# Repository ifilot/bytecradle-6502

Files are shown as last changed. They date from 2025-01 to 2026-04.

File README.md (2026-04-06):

# ByteCradle 6502



The **ByteCradle 6502** is a **single-board computer (SBC)** platform designed
for understanding and experimenting with **simple operating systems** on **8-bit
hardware**. Built around the **WDC 65C02** microprocessor, it provides a
hands-on platform for studying **system initialization, memory management,
device interfacing, and file system handling**.

> [!NOTE]  
> The source code for the ByteCradle 6502 operating system for the Mini is found
> in [a separate repository](https://github.com/ifilot/bytecradle-6502-operating-system).

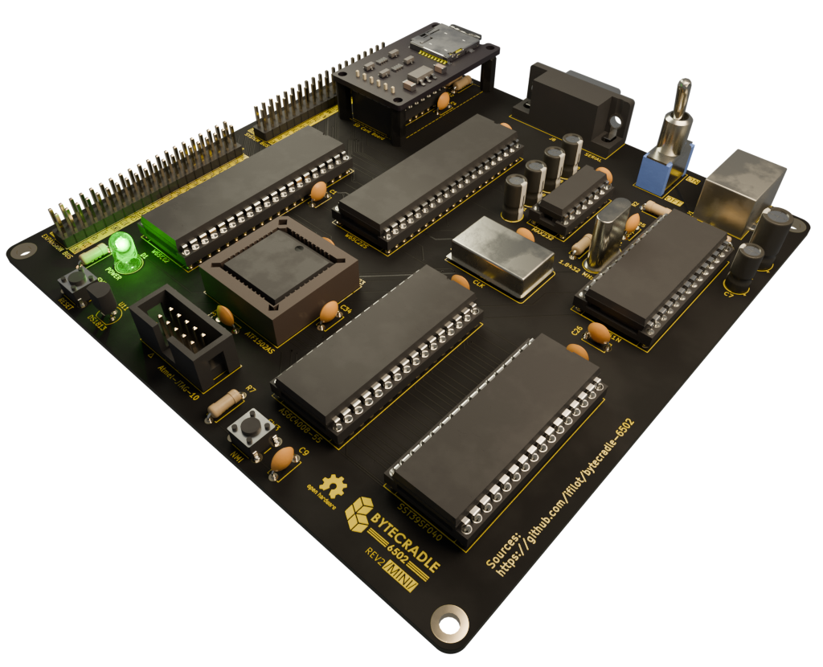
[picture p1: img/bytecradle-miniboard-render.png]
render top


## 📋 Table of Contents

- [BYTECRADLE 6502](#bytecradle-6502)
- [Overview](#overview)
  - [Shared Components](#shared-components)
- [Tier Comparison](#tier-comparison)
- [Obtaining PCBs](#obtaining-pcbs)
- [Download ROMs](#download-roms)
- [License](#license)
  - [Software](#software)
  - [Hardware](#hardware)
- [Contributing](#contributing)
- [Acknowledgements](#acknowledgements)

## Overview

Both SBCs share a common design philosophy — to provide a straightforward and
accessible 65C02 system, while exploring different levels of hardware
capability.

### Shared Components

- **CPU**: WDC 65C02
- **I/O**: WDC 65C51 Asynchronous Communications Interface Adapter (ACIA)

## Tier Comparison

This project offers two tiers of single board computers (SBCs), each tailored to
different levels of complexity and expandability:

- **Tiny SBC** (top): A simple, compact design ideal for learning or small
  embedded projects.
- **Mini SBC** (bottom): A more capable version with bank switching, SD card
  storage, and an expansion bus using the 65C22 Versatile Interface Adapter
  (VIA).

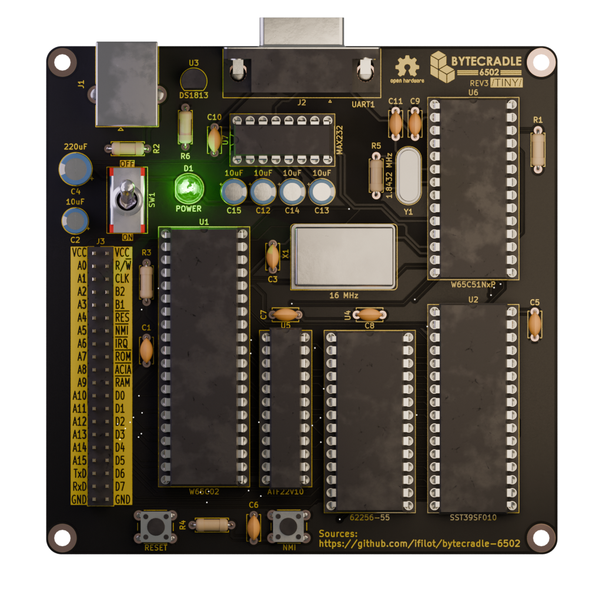
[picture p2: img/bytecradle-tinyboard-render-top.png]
render top


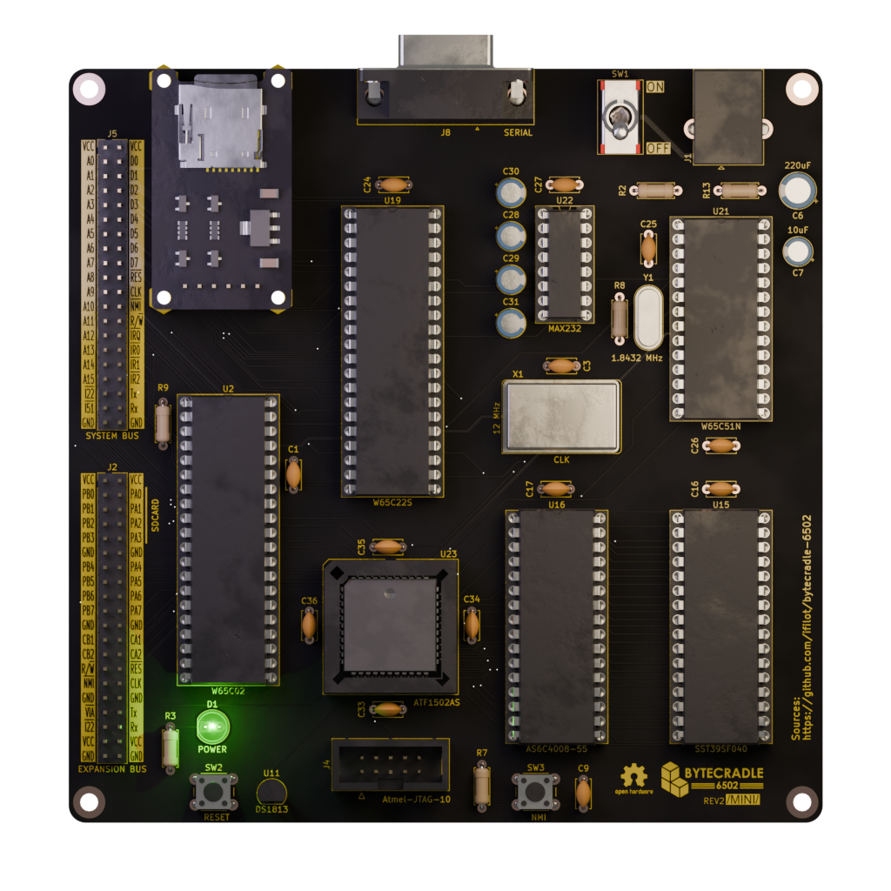
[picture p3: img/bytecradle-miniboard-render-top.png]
render top


| Feature | Tiny SBC | Mini SBC |
|---|---|---|
| **PCB** | Two layer | Four layer |
| **RAM** | 32 KiB | 512 KiB (bank switched) |
| **ROM** | 32 KiB | 512 KiB (bank switched) |
| **Bank Switching** | No | Yes - 64 x 8 Kib banks |
| **SD Card Support**  | No | Yes - Using WDC 65C22 VIA |
| **I/O Interface** | WDC 65C51 ACIA | WDC 65C51 ACIA |
| **Expansion Options**| Exposes system bus | Exposes system bus and VIA bus |

## Obtaining PCBs

You can have the ByteCradle PCBs manufactured at any PCB fabrication service of
your choice. However, for convenience and ease of ordering, we recommend using
[PCBWay](https://www.pcbway.com).

The following links will take you directly to the shared projects on PCBWay, where you can order the boards:

- [Order the Mini Board from PCBWay](https://www.pcbway.com/project/shareproject/ByteCradle_6502_Mini_Board_becc5f96.html)
- [Order the Tiny Board from PCBWay](https://www.pcbway.com/project/shareproject/ByteCradle_6502_Tiny_Board_7606b02a.html)

> [!NOTE]  
> These links direct you to the official project pages for the Mini and Tiny
> Boards on PCBWay.

## Download ROMs

Below are the available ROM images for use with the ByteCradle single-board
computers. These ROMs can be flashed onto your device depending on the board you
are using.

- **[TinyROM](https://github.com/ifilot/bytecradle-6502/releases/download/tinyrom-latest/tinyrom.bin)**  
  A lightweight ROM designed specifically for the Tiny Board. Ideal for minimal
  setups, testing, or basic 6502 development.

> [!IMPORTANT]  
> Make sure to select the appropriate ROM for your board model. Flashing the
> incorrect ROM may result in system instability.

## License

### Software

All software (including ROM code, tools, and firmware) in this repository is
licensed under the [GNU General Public License v3.0](LICENSE-GPL).

This means:
- You are free to use, modify, and share the software.
- If you distribute modified versions, you must also release them under the GPLv3.

### Hardware

All hardware design files (schematics, PCB layouts, bills of materials, etc.)
are licensed under the [CERN Open Hardware License v2 - Weakly Reciprocal
(CERN-OHL-W)](LICENSE-HARDWARE).

This means:
- You may study, modify, manufacture, and distribute the hardware freely.
- If you distribute a modified version, you must share your changes under the
  same license.

## Contributing

Contributions, ideas, and improvements are always welcome. Open an issue or
submit a pull request to get involved!

## Acknowledgements

We gratefully acknowledge [PCBWay](https://www.pcbway.com/) for their generous
support in sponsoring the prototype PCB manufacturing of the Mini Board. Their
assistance helped accelerate the development and testing of the hardware, and we
appreciate their commitment to supporting open hardware projects.

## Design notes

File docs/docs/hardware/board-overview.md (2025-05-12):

# Board Overview

## Tier System Overview

ByteCradle’s hardware platform is designed with flexibility and accessibility in
mind, offering a scalable ecosystem for retro computing enthusiasts, embedded
developers, and educational environments. It features a tiered architecture to
accommodate both minimalistic setups and more capable systems, ensuring a smooth
learning curve while supporting increasingly complex applications. Each tier is
carefully engineered to balance performance, expandability, and simplicity,
making it easy to dive into 65xx-based system design, from first experiments to
advanced custom builds.

### Tiny SBC

- Simplified design with a small footprint.
- Memory: 32 KiB RAM and 32 KiB ROM.
- Programmable logic: Utilizes small PLDs to minimize discrete components.
- Ideal for learning, experimentation, and small embedded projects.

[🔍 View schematic](schematics-layout.md#tiny)

<p align="center">
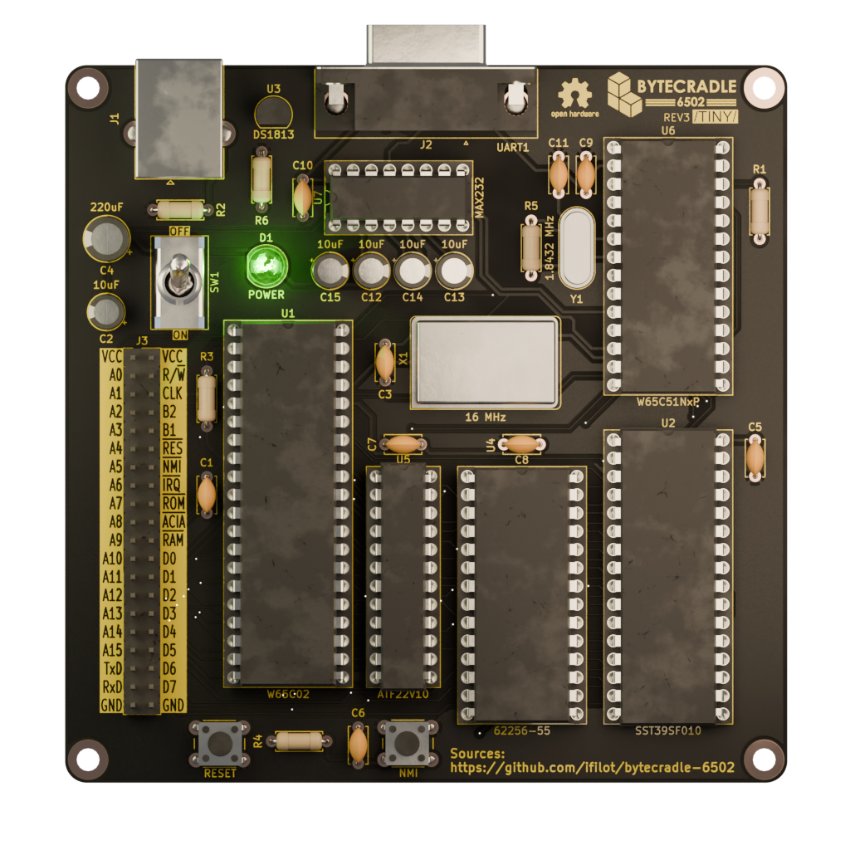
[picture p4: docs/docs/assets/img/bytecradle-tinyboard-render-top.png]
  
</p>

### Mini SBC

- Advanced design with bank switching for greater memory capabilities.
- Memory: 512 KiB of RAM and 512 KiB of ROM (bank-switched).
- Programmable logic: Built around CPLDs for greater integration.
- Includes a 65C22 VIA to interface with an SD card for persistent
  storage and potential peripheral expansion.
- Perfect for exploring larger applications, file systems, and
  system-level programming.

[🔍 View schematic](schematics-layout.md#tiny)

<p align="center">
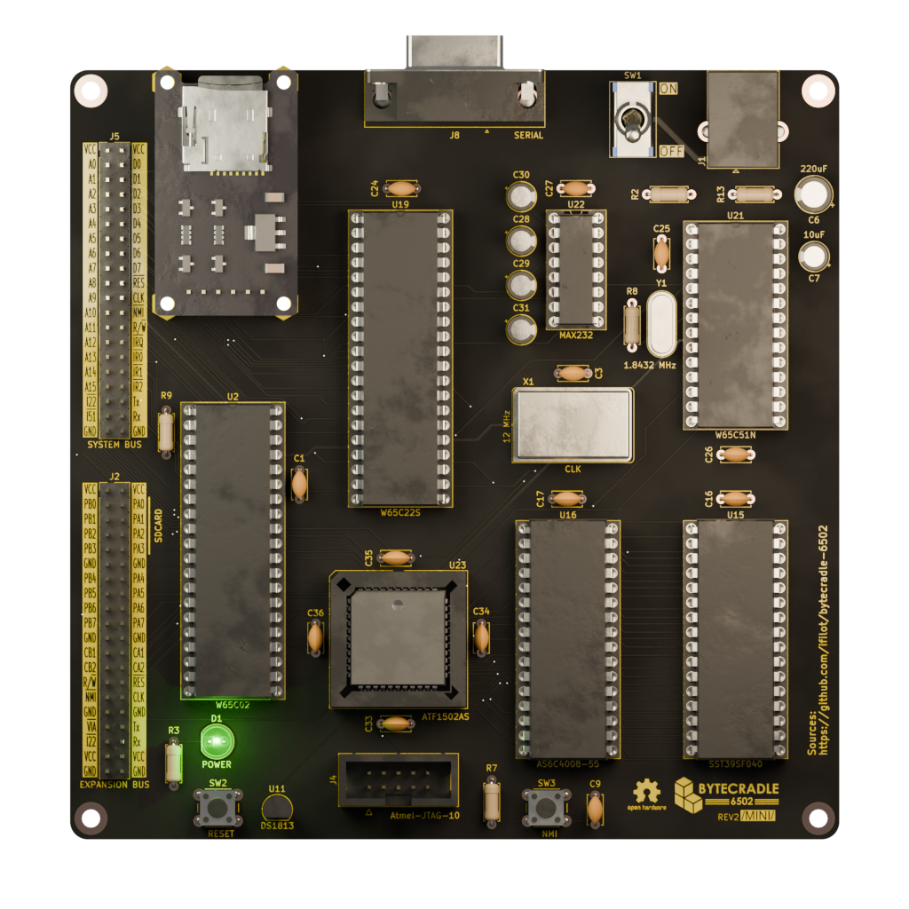
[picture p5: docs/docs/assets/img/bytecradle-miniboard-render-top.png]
  
</p>

## Feature Comparison

| Feature | Tiny SBC | Mini SBC |
|---|---|---|
| **Frequency** | 16 MHz | 12 MHz |
| **RAM** | 32 KiB | 512 KiB (bank switched) |
| **ROM** | 32 KiB | 512 KiB (bank switched) |
| **Bank Switching** | ❌ | ✅ (64 × 8 KiB banks) |
| **SD Card Support** | ❌ | ✅ (via 65C22 VIA) |
| **Serial Interface** | 65C51 ACIA | 65C51 ACIA |
| **I/O mapping** | ATF22V10 | ATF1502 |
| **Expansion Options**  | Exposes system bus | Exposes system bus and VIA bus |

!!! note 
    The Tiny Board operates at a higher clock frequency due to its
    optimized internal timings. Unlike the Mini Board, the Tiny Board lacks bank
    switching, which reduces propagation delay and enables stable performance at
    16 MHz. In contrast, the Mini Board's architecture limits reliable operation
    to 12 MHz. However, certain speed enhancements—particularly for the ACIA—are
    possible. Details can be found in the 
    [hardware customization section](../advanced-topics/hardware-customizations.md).

## Programmable logic

Both ByteCradle boards use programmable logic devices, a ATF22V10 PLD in the
:material-chip: **TINY** board and a ATF1502 CPLD for the :material-chip:
**MINI** board. These chips handle essential control logic like address
decoding, chip selects, and bank switching. These devices replace traditional
discrete logic chips (such as 74-series TTL), resulting in faster, more compact,
and more reliable designs.

### Tiny Board - ATF22V10

The :material-chip: **TINY** Board uses an ATF22V10 PLD to implement address
decoding and I/O mapping for RAM, ROM, and the ACIA serial interface. This chip
allows tight integration of logic without chaining multiple discrete components,
which reduces propagation delays. Its internal logic can respond in under 10 ns,
enabling the system to run stably at 16 MHz—much faster than typical retro
systems.

### Mini Board - ATF1502

The :material-chip: **MINI** Board uses an ATF1502 CPLD, which offers
significantly more logic resources. It handles complex tasks like dynamic RAM
and ROM bank switching, peripheral selection, and reading/writing to the bank
registers. Updates can be made through JTAG without changing hardware. The
CPLD's deterministic timing is critical for maintaining stability at 12 MHz.

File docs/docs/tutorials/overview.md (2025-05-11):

# Tutorials

<div class="grid cards">

  <div class="card">
    <h3><a href="../inline-assembler/">🧩 Inline Assembler</a></h3>
    <p>Learn how to code 6502 directly on your ByteCradle Board using inline-assembler available via the Monitor.</p>
  </div>

  <div class="card">
    <h3><a href="../hello-world-assembly/">📟 Hello World (Assembly)</a></h3>
    <p>Write your first stand-alone 6502 program in pure assembly and run it on the ByteCradle platform.</p>
  </div>

  <div class="card">
    <h3><a href="../hello-world-c/">💬 Hello World (C)</a></h3>
    <p>Create a minimal C program with cc65 and explore the basics of linking and deploying to ByteCradle.</p>
  </div>

</div>

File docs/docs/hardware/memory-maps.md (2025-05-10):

# Memory Maps

## Tiny Board

The :material-chip: **TINY** board uses a flat 64 KiB memory map typical of
65C02-based systems. The first 256 bytes (`$0000–$00FF`) are Zero Page RAM,
followed by the stack at `$0100–$01FF`. The range `$0200–$03FF` is reserved for
OS use, while `$0400–$7EFF` serves as general-purpose RAM.

A small I/O region at `$7F00–$7FFF` includes only `$7F04–$7F07`, which is
connected to a 65C51 ACIA UART for serial communication. The remainder of
the I/O space is currently unused but mapped to RAM, meaning it is technically
accessible for reads and writes. However, using this area is not
recommended, as future hardware revisions may repurpose it. Users may also
reconfigure the address decoding logic by updating the ATF22V10 chip to
change or expand the I/O mapping as needed.

The upper 32 KiB (`$8000–$FFFF`) is mapped to ROM, containing system
firmware such as a monitor or BASIC interpreter.

| Address Range | Size | Description |
|:---|:---|:---|
| `$0000-$00FF` | 256 bytes  | **Zero Page RAM** |
| `$0100-$01FF` | 256 bytes  | **Stack** |
| `$0200-$03FF` | 512 bytes  | **Reserved (OS Use)** |
| `$0400-$7EFF` | ~31 KiB | **General Purpose RAM** |
| `$7F00-$7F03` | 4 bytes | **Unused / Reserved** |
| `$7F04-$7F07` | 4 bytes | **ACIA (UART)** |
| `$7F08-$7FFF` | 248 bytes  | **Unused / Reserved** |
| `$8000-$FFFF` | 32 KiB | **ROM** |

## Mini Board

The :material-chip: **MINI** board features a flexible 64 KiB memory map
designed to support both fixed and bank-switched memory regions. The lower
memory (`$0000–$7EFF`) is primarily RAM, with the first 256 bytes
(`$0000–$00FF`) allocated as **Zero Page**, and the next 256 bytes
(`$0100–$01FF`) serving as the stack. Addresses `$0200–$07FF` are reserved for
OS-level functionality, while the remainder up to `$7EFF` is available as
general-purpose RAM, implemented across fixed banks 0–3.

The region `$7F00–$7FFF` is dedicated to memory-mapped I/O, divided into
four 64-byte blocks using only address lines A6 and A7. The first block
(`$7F00–$7F3F`) connects to a 65C51 ACIA for serial communication, while the
second (`$7F40–$7F7F`) maps to a 6522 VIA. The remaining two blocks
(`$7F80–$7FBF` and `$7FC0–$7FFF`) are used to write to the ROM and RAM
bank registers, respectively.

The upper half of the address space is split between banked and fixed
ROM/RAM. The ranges `$8000–$9FFF` and `$A000–$BFFF` are bank-switched RAM
and ROM windows, supporting 64 banks each. The final 16 KiB (`$C000–$FFFF`) is
mapped to fixed ROM, permanently connected to banks 0 and 1, containing 
critical system firmware.

!!! warning 
    The bank-switched ROM and RAM regions (`$A000–$BFFF` and
    `$8000–$9FFF`) share the same physical memory space as the fixed ROM
    (`$C000–$FFFF`) and fixed RAM (`$0000–$7EFF`), respectively. This means that
    selecting ROM banks 0–1 or RAM banks 0–3 will expose the **same
    physical memory** already mapped in the fixed regions. For example, if RAM
    bank 0 is selected, writes may unintentionally modify the stack or zero
    page; selecting ROM bank 0 might interfere with the interrupt vectors or
    firmware routines.  

    While overlapping ROM banks are less problematic—since ROM is typically
    read-only and cannot be written to—it can still cause confusion or redundancy if
    the same code or data appears in both fixed and banked areas. It is strongly
    recommended to begin using **RAM banks from 4 upwards** and **ROM banks from 2
    upwards** to avoid overlapping with fixed memory areas and ensure predictable
    behavior.

| Address Range | Size | Description |
|:---|:---|:---|
| `$0000-$00FF` | 256 bytes  | **Zero Page RAM** |
| `$0100-$01FF` | 256 bytes  | **Stack** |
| `$0200-$07FF` | 512 bytes  | **Reserved** (used by BCOS) |
| `$0800-$7EFF` | 30 KiB | **General Purpose RAM (Fixed, Banks 0–3)** |
| `$7F00-$7F3F` | 64 bytes | **ACIA (UART)** |
| `$7F40-$7F7F` | 64 bytes | **VIA** |
| `$7F80-$7FBF` | 64 bytes | **ROM Bank Register** |
| `$7FC0-$7FFF` | 64 bytes | **RAM Bank Register** |
| `$8000-$9FFF` | 8 KiB | **Bank-switched RAM Window (Banks 0–63)** |
| `$A000-$BFFF` | 8 KiB | **Bank-switched ROM Window (Banks 0–63)** |
| `$C000-$FFFF` | 16 KiB | **Fixed ROM (Banks 0–1 mapped permanently)** |

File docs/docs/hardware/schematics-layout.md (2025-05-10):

# Board Schematics

The schematics for the :material-chip: **TINY** and :material-chip: **MINI**
boards are provided in SVG format, which allows for infinite scaling without any
loss of detail. This makes them ideal for inspection, printing, or embedding in
other documents. Simply click on any image to view it full-size in your browser
or download it directly for offline use.

## Tiny

Circuit schematic of Mini BOARD page 1

## Mini

Circuit schematic of Mini BOARD page 1

Circuit schematic of Mini BOARD page 2

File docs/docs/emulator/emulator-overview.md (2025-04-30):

# Emulator Overview

Developing software for the ByteCradle 6502 platform without an emulator
involves a tedious and repetitive workflow: you would need to cross-assemble or
cross-compile your source code, flash it onto a ROM, physically insert that ROM
into the board, and then run the board to test your code. Each cycle can take
several minutes and is prone to errors, making rapid development and testing
difficult.

The `bc6502emu` emulator removes these barriers by allowing you to run and test
your 6502 code directly on a modern computer. It integrates cleanly into your
development workflow and enables fast iteration without the need for physical
hardware during the early stages of development.

## Benefits of Using an Emulator

- **Rapid testing and iteration**: Instantly test code changes without flashing or hardware interaction, dramatically reducing development time.
- **Safe and controlled environment**: Reproducible and isolated, ideal for debugging, testing edge cases, and avoiding hardware wear or damage.
- **Simplified debugging**: Observe program behavior, simulate input, and analyze results using standard tools on your development machine.
- **Development without hardware**: Start writing and validating software even before hardware is available or finalized.
- **Automation and integration**: Easily integrate into build systems and CI pipelines for automated testing and validation.

## Introducing `bc6502emu`

`bc6502emu` is a lightweight emulator designed specifically for the ByteCradle
6502 platform. It supports the two board variants:

- **tiny** – a minimal configuration without SD card storage.
- **mini** – includes SD card image support for simulating file I/O and the 65C22 versatile interface adapter.

With `bc6502emu`, you can:

- Run 6502 binaries directly from your development environment.
- Simulate SD card behavior (mini variant).
- Configure the emulated CPU clock speed.
- Provide terminal input for programs that rely on user interaction.

!!! tip "Ready to get started?"
    Go to the [Installing Emulator](./installing-emulator.md) page to compile and run the emulator.

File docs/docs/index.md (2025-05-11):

# Welcome to ByteCradle 6502 Documentation

The **ByteCradle 6502** is a **single-board computer (SBC)** platform built
around the **WDC 65C02** microprocessor.   It is designed for learning and
experimenting with **simple operating systems** on **8-bit hardware**. Whether
you are new to 8-bit computers or an experienced hardware tinkerer, ByteCradle
offers an accessible and expandable environment to explore these topics.

<p align="center">
  
</p>

## 🚀 Quick Start

<div class="grid cards" align="center">

  <div class="card">
    <h3><a href="getting-started/required-tools">🚀 Getting Started</a></h3>
    <p>Learn how to assemble the board, power up safely, and run your first program.</p>
  </div>

  <div class="card">
    <h3><a href="hardware/board-overview/">🖥️ Hardware Overview</a></h3>
    <p>Dive deep into the hardware design, schematics, and engineering decisions behind ByteCradle.</p>
  </div>

  <div class="card">
    <h3><a href="software/software-overview/">💾 Software Overview</a></h3>
    <p>Explore the codebase and development decisions that power ByteCradle's software stack.</p>
  </div>

  <div class="card">
    <h3><a href="emulator/emulator-overview/">🧪 Emulator</a></h3>
    <p>Install and use the emulator to prototype, test, and debug your 65C02 programs.</p>
  </div>

  <div class="card">
    <h3><a href="tutorials/overview/">💡 Tutorials</a></h3>
    <p>Start coding! Follow step-by-step guides for writing assembly, peripherals control, and debugging.</p>
  </div>

  <div class="card">
    <h3><a href="advanced-topics/expanding-the-system/">⚙️ Advanced Topics</a></h3>
    <p>Explore system expansion, hardware mods, and building more sophisticated applications.</p>
  </div>

</div>

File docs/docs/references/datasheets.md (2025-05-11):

# Datasheets

This page provides quick access to technical datasheets for the key components
used in the ByteCradle platform. These documents include pinouts, electrical
characteristics, timing diagrams, and functional descriptions.

## 🕹️ Core Components

- [W65C02S – 8-bit CMOS Microprocessor](../assets/datasheets/w65c02s-2572.pdf)
- [W65C22 – Versatile Interface Adapter (VIA)](../assets/datasheets/w65c22.pdf)
- [W65C51N – Asynchronous Communications Interface Adapter (ACIA)](../assets/datasheets/w65c51n.pdf)

## 🧠 Memory

- [AS6C4008 – 512K x 8 Low Power CMOS SRAM](../assets/datasheets/AS6C4008.pdf)
- [AS6C62256 – 32K x 8 Low Power CMOS SRAM](../assets/datasheets/AS6C62256.pdf)
- [SST39SF0x0 – Parallel Flash Memory Series](../assets/datasheets/sst39sf0x0.pdf)

## 🧩 Programmable Logic

- [ATF1502AS – CPLD (Complex Programmable Logic Device)](../assets/datasheets/ATF1502AS.pdf)
- [ATF22V10 – High-Performance PLD](../assets/datasheets/atf22v10.pdf)

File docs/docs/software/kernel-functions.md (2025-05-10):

# Kernel functions

The system exposes a set of core kernel functions at fixed memory addresses
located just below the 6502 vector table. This area is referred to as the **jump
table**.

Each jump table entry is a 3-byte `JMP` instruction that redirects to the actual
implementation of a function. This design allows system programs and user
applications to call kernel routines via **stable, absolute addresses**,
regardless of where the underlying code is actually located.

## How It Works

The jump table starts at address `$FFE5`, with each function occupying 3 bytes
(the size of a `JMP` absolute instruction). For example:

```assembly
jsr $FFE5  ; call putstr
```

This instruction jumps to the putstr routine, allowing the user to print a
string without needing to know where putstr is implemented in memory. This makes
the jump table a forward-compatible interface to the kernel.

## Overview jump table

Below is an overview of currently available jump table entries:

| Label | Address | Description | Input Registers | Garbled Registers |
|---|---|---|---|---|
| `putstr` | `$FFE5` | Prints a null-terminated string. | `X:A` = High:Low pointer to string | `A`, `X`, `Y` |
| `putstrnl` | `$FFE8` | Prints a null-terminated string followed by a CRLF. | `X:A` = High:Low pointer to string | `A`, `X`, `Y` |
| `putch` | `$FFEB` | Outputs a single character to ACIA. | `A` = Character | *None* |
| `newline`  | `$FFEE` | Prints carriage return and line feed. | - | *None* |
| `puthex` | `$FFF1` | Prints a byte in hexadecimal format. | `A` = Byte to print | *None* |
| `putdec` | `$FFF4` | Prints a byte in decimal format. | `A` = Byte to print | `X`, `Y` |
| `getch` | `$FFF7` | Retrieves a character from input buffer. | — | `A` |

!!! note 
    The jump table is exactly the same for both the :material-chip: **TINY**
    and :material-chip: **MINI** boards.

!!! warning 
    *Garbled* refers to CPU registers whose contents
    are **modified or overwritten** by a routine and are **not restored** before
    returning. This means the calling code **should not rely on the original
    values** of these registers after the routine executes.

    For example, if a function garbles register `X`, then any value that was in 
    `X` before the function call may be lost and should not be assumed valid 
    afterward. To preserve important register values across such calls, the 
    caller is responsible for saving and restoring them (e.g., using `PHA`, 
    `PHX`, `PHY` and their corresponding pull instructions).

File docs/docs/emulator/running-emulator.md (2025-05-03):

# Running the Emulator

Once compiled, you can run the emulator with the following syntax (adjust
accordingly for your paths):

```bash
./bc6502emu --board <tiny|mini> \
--rom <path_to_rom> \
[--sdcard <path_to_sdcard>] \
[--clock <mhz>]
```

## Arguments

| Argument | Description | Required |
|:---|:---|:---|
| `-b, --board` | Select the board type: `tiny` or `mini`. | Yes |
| `-r, --rom` | Path to the ROM file to load. | Yes |
| `-s, --sdcard` | Path to the SD card image (only for `mini`). | No |
| `-c, --clock` | CPU clock speed in MHz (default: 16.0 MHz). | No |

## Example Usage

To run the emulator with the `tiny` board:

```bash
./bc6502emu --board tiny --rom ../../src/tinyrom/tinyrom.bin
```

To run the emulator with the `mini` board and an SD card image:

```bash
./bc6502emu --board mini --rom ../../src/minirom.bin --sdcard ../scripts/sdcard.img --clock 12.0
```

!!! info 
    For running the `/MINI/` board, besides the ROM file, you will also need
    an SD-card image. This SD-card image can be generated using the
    `create_sd.sh` script found in the `emulator/script` folder.

!!! tip 
    For compiling the ROMs, we make use of a `Makefile`. These `Makefile`
    files contain the `make run` instruction which automatically launches the
    ROM in the emulator using the right settings. It does assume that the
    emulator has been compiled in the `build` folder as explained above.

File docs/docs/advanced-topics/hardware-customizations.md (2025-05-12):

# Hardware customization

ByteCradle was built from the ground up with openness and user empowerment in
mind. As an open-source single board computer, it invites users not only to
explore the software but to dive deep into the hardware itself. The system is
designed to be educational, extendable, and hackable—encouraging curiosity and
experimentation at every level.

To support this vision, we provide a number of hardware customization options
that users can implement with basic tools and an understanding of the 6502
platform.

## Upgrading Serial Communication Speed

By default, the ByteCradle board uses a **65C51 ACIA** for serial communication,
clocked by a 1.8432 MHz crystal (or resonator). With the ACIA's fixed ×16
clock divider, this yields a standard 115200 BAUD rate.

For users seeking faster serial communication, this BAUD rate can be increased
by replacing the crystal with a higher frequency one. The following
configurations have been tested and shown to provide stable operation:

| Crystal Frequency | Effective BAUD Rate |
|---|---|
| 1.8432 MHz | 115200 |
| 3.6864 MHz | 230400 |
| 7.3728 MHz | 460800 |

!!! warning
    * If you replace the crystal of the ACIA crystal, you **need** to adjust the
      software accordingly. More information is provided below.
    * When selecting a resonator crystal, ensure it is paired with the 
      appropriate load capacitors to achieve the correct resonance frequency.

To upgrade your board:

1. **Physically replace** the 1.8432 MHz crystal with a compatible 3.6864 MHz or
   7.3728 MHz crystal.
2. **Update your terminal or serial communication software** to match the new
   BAUD rate.
3. **Adjust the initialization script** or system configuration to reflect the
   new BAUD rate. Example code can be found below.

!!! note
    Not all USB-to-Serial adapters or operating systems handle higher
    BAUD rates reliably. Be sure to test stability under your specific setup.

The script below is the default assembly subroutine, found in `io.s` that prints
out a single character to the serial port. If you replace the crystal resonator,
you **need** to adjust the delay value. For example, if you use a Tiny Board
running at 16 MHz with a 7.3728 MHz crystal and a 460800 BAUD rate, you need a
delay of 16e6 * 10 / 460800 / 7 = 50.

```
;-------------------------------------------------------------------------------
; putchar routine
;
; Converves A
;
; Prints a character to the ACIA; note that software delay is needed to prevent
; transmitting data to the ACIA while it is still transmitting.
; At 12 MhZ, we need to wait 12e6 * 10 / 115200 / 7 = 149 clock cycles,
; where the 5 corresponds to the combination of "DEC" and "BNE" taking 5 clock
; cyles.
;
;  4.000 MHz    :  50
; 10.000 MHz    : 124
; 12.000 MHz    : 149 (works on Tiny; works on Mini)
; 16.000 MHz    : 198 (works on Tiny; does *not* work on Mini)
;-------------------------------------------------------------------------------
_putch
putch:
    pha             ; preserve A
    sta ACIA_DATA   ; write the character to the ACIA data register
    lda #149        ; initialize inner loop
@inner:
    nop             ; NOP; 2 cycles
    dec             ; decrement A; 2 cycles
    bne @inner      ; check if zero; 3 cycles
    pla             ; retrieve A from stack
    rts
```

For your convenience, you can consult the table as shown below.

| CPU Clock | ACIA Crystal | BAUD Rate | Delay Cycles |
|---|---|---|---|
| 4.000 MHz | 1.8432 MHz | 115200 | 50 |
|10.000 MHz | 1.8432 MHz | 115200 | 124 |
|12.000 MHz | 1.8432 MHz | 115200 | 149 |
|16.000 MHz | 1.8432 MHz | 115200 | 198 |
| 4.000 MHz | 3.6864 MHz | 230400 | 25 |
|10.000 MHz | 3.6864 MHz | 230400 | 62 |
|12.000 MHz | 3.6864 MHz | 230400 | 74 |
|16.000 MHz | 3.6864 MHz | 230400 | 99 |
| 4.000 MHz | 7.3728 MHz | 460800 | 12 |
|10.000 MHz | 7.3728 MHz | 460800 | 31 |
|12.000 MHz | 7.3728 MHz | 460800 | 37 |
|16.000 MHz | 7.3728 MHz | 460800 | 50 |

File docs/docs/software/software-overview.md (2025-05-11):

# Software Overview

<div class="grid cards">

  <div class="card">
    <h3><a href="../../software/operating-system/">✨ Operating System</a></h3>
    <p>Understand how the operating system manages tasks and interacts with the hardware.</p>
  </div>

  <div class="card">
    <h3><a href="../../software/kernel-functions/">🔧 Kernel Functions</a></h3>
    <p>Explore kernel-level functions that handle modularized input/output operations.</p>
  </div>

  <div class="card">
    <h3><a href="../../software/building-programs/">🛠️ Building Programs</a></h3>
    <p>Learn how to write, compile, and deploy C and assembly programs using the cc65 toolchain.</p>
  </div>

</div>

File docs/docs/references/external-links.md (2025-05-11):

# External Links

This page contains a collection of helpful external resources related to the 6502 microprocessor, covering documentation, tools, tutorials, and communities.

## 🧠 General Information

- [6502.org](http://www.6502.org)  
  A comprehensive site dedicated to the 6502, including datasheets, hardware projects, and programming guides.

- [The MOS 6502 Wikipedia Entry](https://en.wikipedia.org/wiki/MOS_Technology_6502)  
  A good general overview of the 6502’s history, architecture, and applications.

## 📚 Programming Resources

- [Easy 6502](https://skilldrick.github.io/easy6502/)  
  An interactive tutorial for learning 6502 assembly language from scratch.

- [CC65 Toolchain](https://cc65.github.io/)  
  Official documentation for the cc65 C compiler and suite targeting 6502 systems.

- [The 6502 Instruction Set](http://www.6502.org/tutorials/6502opcodes.html)  
  Detailed breakdown of opcodes and addressing modes.

- [Ben Eater’s 6502 Computer Series](https://www.youtube.com/playlist?list=PLowKtXNTBypFbtuVMUVXNR0z1mu7dp7eH)
  A fantastic hands-on video series building a 6502 computer from scratch and programming it.

## 🛠️ Tools

- [Visual 6502](https://visual6502.org/)  
  A transistor-level simulation of the 6502 CPU—see it run in your browser.

- [Emulators and Simulators (6502.org)](http://www.6502.org/tools/emu/)  
  A list of software emulators and simulators for developing and testing 6502 code.

## 💬 Community

- [6502.org Forums](http://forum.6502.org/)  
  A community of hobbyists and experts discussing hardware, software, and projects.

- [r/6502 on Reddit](https://www.reddit.com/r/6502/)  
  A Reddit community for sharing 6502 tips, projects, and questions.

Have a great resource to suggest? Feel free to open a pull request or issue!

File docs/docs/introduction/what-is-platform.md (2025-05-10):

# Introducing the ByteCradle 6502 Platform

In the 1970s, the future of personal computing was **8-bit**. Microcomputers and
home computers of the era almost universally began with 8-bit processors. The
legacy of this era still shapes computing today — the prominence of the **byte**
as a standard unit of storage and data is a direct inheritance from these early
systems.

The **ByteCradle 6502** embraces this legacy. It is a hands-on, 8-bit computing
platform built around the **WDC 65C02** microprocessor, a modern variant of the
classic MOS 6502. Designed for hobbyists, educators, and retrocomputing
enthusiasts, the **ByteCradle 6502** offers a practical gateway into low-level
system design, assembly programming, and hardware experimentation — all in the
spirit of the early home computer revolution.

## Tier System Overview

The platform is structured into two distinct tiers, each designed to balance
functionality and cost. Lower tiers offer more affordable options, but with
reduced feature sets compared to higher tiers.

### Tiny SBC

<p align="center">
  
</p>

- 65C02 processor running at **16 MHz**
- Simplified design with a small footprint.
- Memory: 32 KiB RAM and 32 KiB ROM.
- I/O communication via a 65C51 ACIA.
- Programmable logic: Utilizes small PLDs to minimize discrete components.
- Ideal for learning, experimentation, and small embedded projects.

### Mini SBC

<p align="center">
  
</p>

- 65C02 processor running at **12 MHz**
- Advanced design with bank switching for greater memory capabilities.
- Memory: 512 KiB of RAM and 512 KiB of ROM (bank-switched).
- I/O communication via a 65C51 ACIA.
- Programmable logic: Built around CPLDs for greater integration.
- Includes a 65C22 VIA to interface with an SD card for persistent
  storage and potential peripheral expansion.
- Perfect for exploring larger applications, file systems, and
  system-level programming.

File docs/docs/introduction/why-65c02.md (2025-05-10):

# Why the 65C02?

<p align="center">
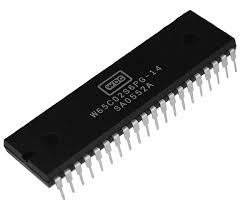
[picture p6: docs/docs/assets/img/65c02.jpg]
  <br>
  65C02 processor from Western Design Center<br>
</p>

## Choosing the Right CPU

At the outset of this project, one of the most critical decisions was selecting
a CPU architecture. Several classic 8-bit and 16-bit processors were considered
— notably the **MOS 6502**, **Zilog Z80**, and **Intel 8088/8086**.

Each of these CPUs played a foundational role in early personal computing.
However, important practical considerations shaped the final choice:

- The **8088/8086**, though historically significant, is no longer in
  production.
- The **Z80**, another strong contender, also recently ceased production —
  though both it and the 8086 remain available through surplus and legacy
  channels.
- The **WDC 65C02**, a modern CMOS variant of the original 6502, is **still in
  active production**. It not only has robust commercial support but also
  carries the legacy of influential systems like the **Apple II**, **Commodore
  64**, **BBC Micro**, and **NES**.

This combination of **availability**, **legacy**, and **technical elegance**
made the 65C02 a natural choice.

## Instruction Set Simplicity

One of the most compelling arguments in favor of the 6502 — especially for a
learning-oriented platform — is its **simplicity**. Its architecture and
instruction set are compact and easy to grasp, making it particularly
approachable for those new to assembly language or low-level system design.

Here's a comparative look at instruction set sizes:

| CPU | Approximate Number of Instructions | Notes |
|---|---|---|
| 6502 | ~56 | Small, minimal instruction set; easy to memorize |
| 65C02 | ~70 | Enhanced 6502 with additional instructions and fixed quirks |
| 65C816 | ~92 | 16-bit extension of 65C02; backward-compatible, adds new registers |
| 8080 | ~78 | Slightly more complex, more registers than 6502 |
| Z80 | ~158 | Includes extended opcodes, prefixes, and register pairs |
| 8086/88  | ~133 | 16-bit instructions, multi-byte ops, complex syntax and segments |

!!! note 
    Instruction counts are approximate because architectures differ in how
    they handle prefixes, variants, addressing modes, and unofficial or
    undocumented opcodes. Extended CPUs (like Z80 or 65C816) often reuse base
    instructions with added functionality.

While instruction count isn't the sole measure of complexity, it does reflect
how **minimal and focused** the 6502 is. In contrast, the 8080 and Z80 offer
richer feature sets that can also present steeper learning curves.

!!! note "Subjectivity note" 
    The ease of programming in assembly is naturally a
    matter of opinion. However, there is broad consensus that the 6502 is
    **beginner-friendly**, largely due to its straightforward instruction set
    and predictable behavior.

By building this platform around the 6502, we aim to blend **historical
relevance** with **practical accessibility**, offering a compelling environment
for both exploration and education in low-level computing.

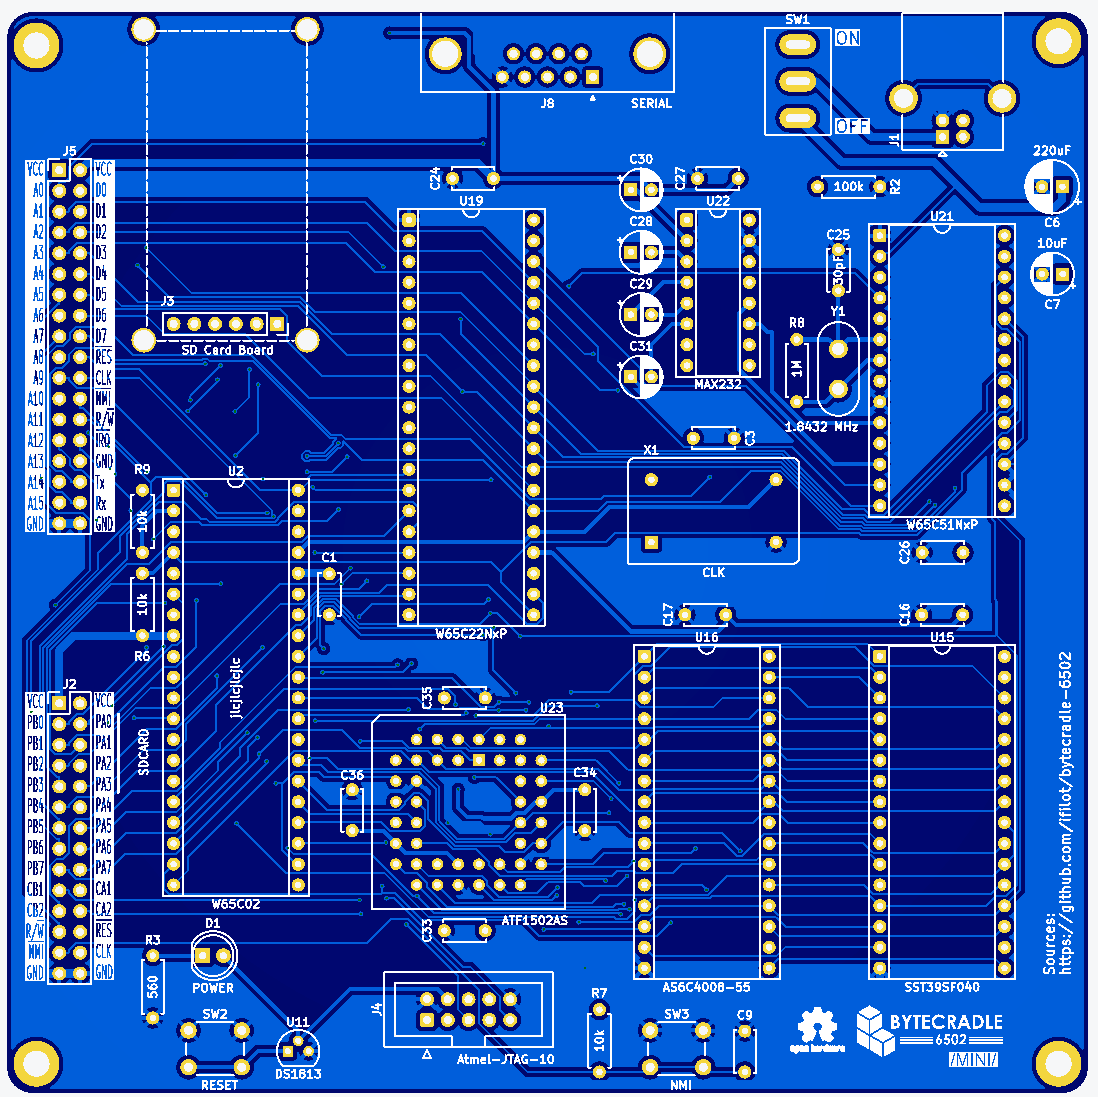
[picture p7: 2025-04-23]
img/bytecradle-mini.PNG

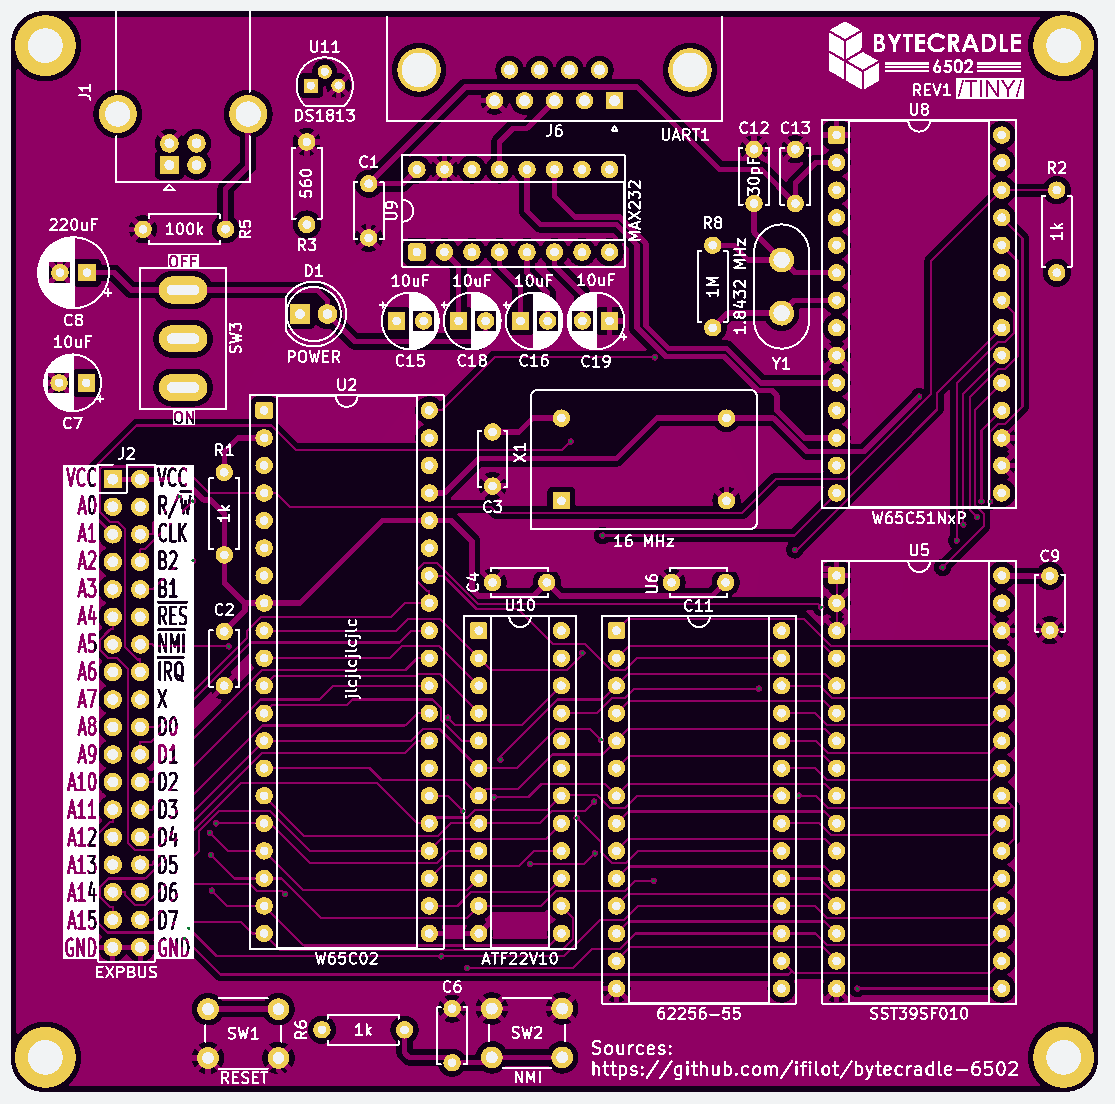
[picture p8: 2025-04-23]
img/bytecradle-tiny.PNG

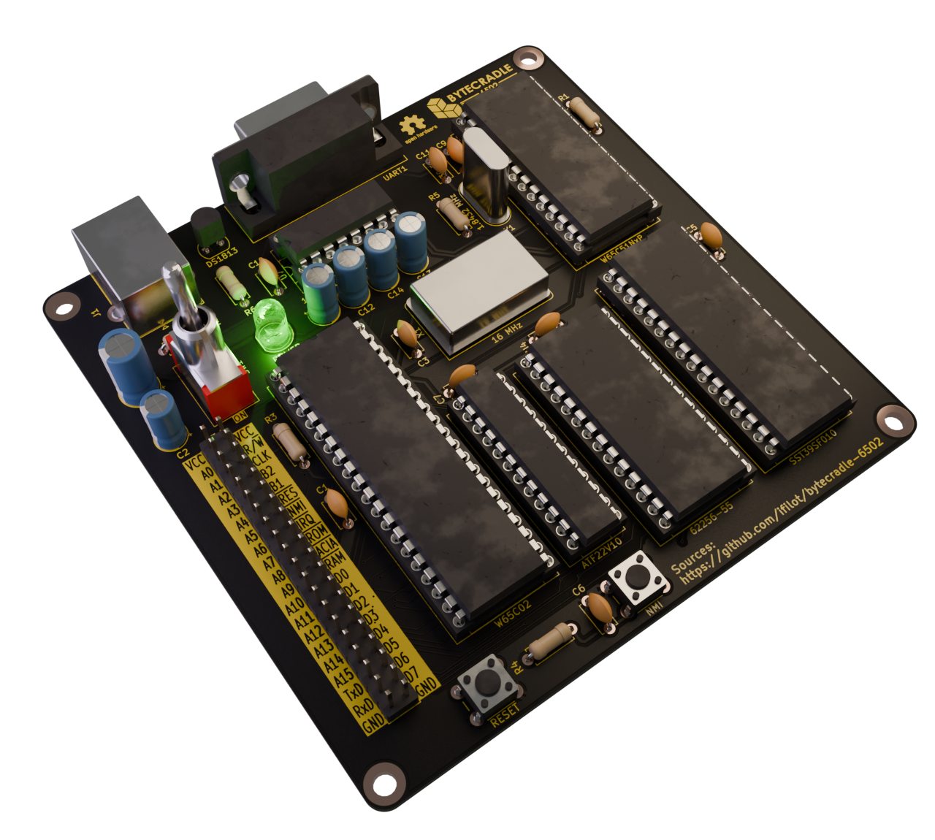
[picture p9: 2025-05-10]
img/bytecradle-tinyboard-render.png

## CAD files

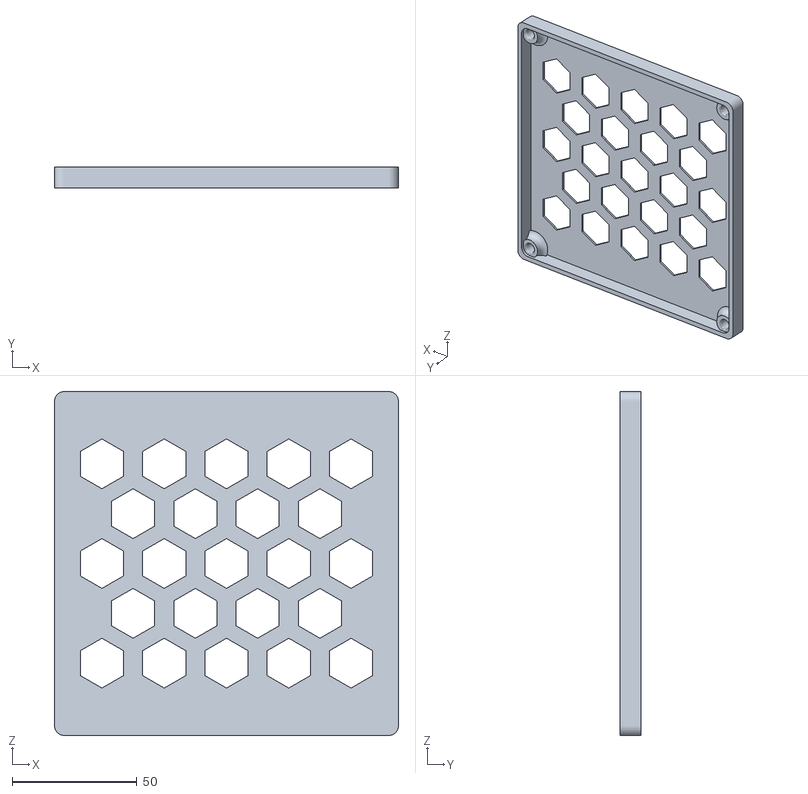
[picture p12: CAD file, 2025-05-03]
baseplates/miniboard/miniboard_baseplate.stl
138.1 x 8.51 x 138.1

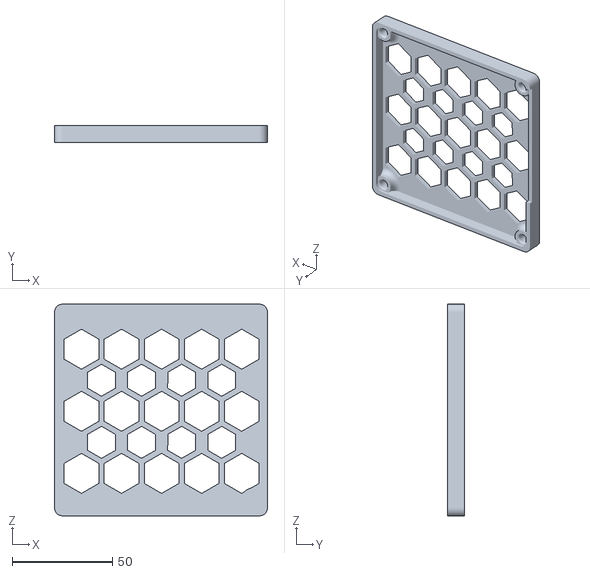
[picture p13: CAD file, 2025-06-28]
baseplates/tinyboard/tinyboard_baseplate_spareout.stl
106.3 x 8.51 x 105.7

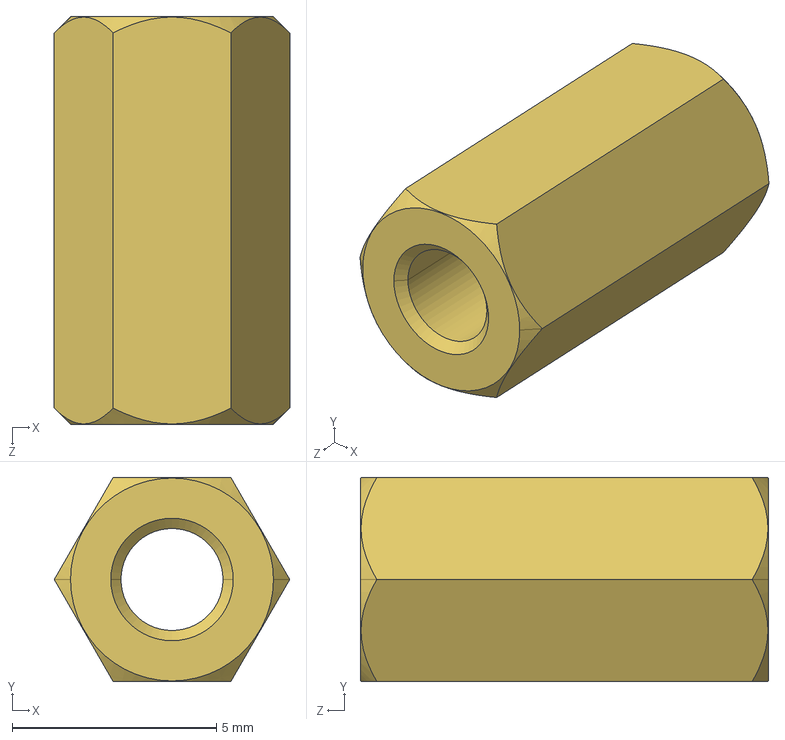
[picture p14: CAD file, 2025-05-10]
pcb/components/M3_F_TO_F_10MM_STANDOFF.STEP
5.77 x 5.00 x 10.0 mm

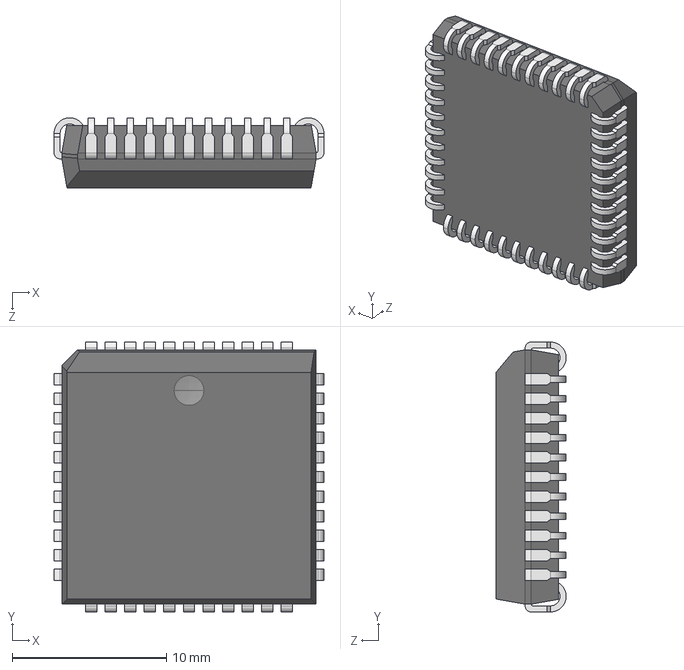
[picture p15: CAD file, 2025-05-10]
pcb/components/PLCC44.STEP
17.5 x 17.5 x 4.57 mm

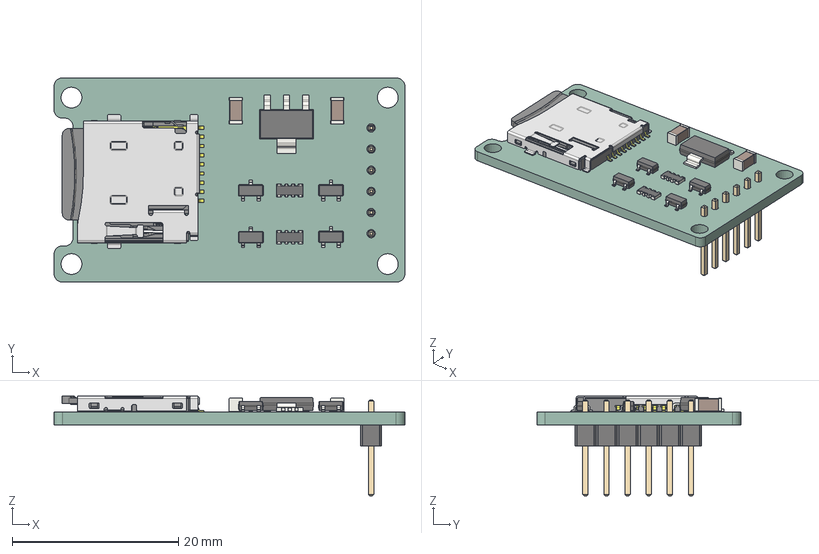
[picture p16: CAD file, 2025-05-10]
pcb/components/sdcard-adapter.step
42.2 x 24.5 x 12.0 mm
SOT-23 x 4
Case^MicroSD_Socket
Insert^MicroSD_Socket
Brace^MicroSD_Socket
Spring^MicroSD_Socket
Lid^MicroSD_Socket
Pin_Middle^MicroSD_Socket x 5
Pin_Short^MicroSD_Socket
Pin_Long^MicroSD_Socket x 2
MicroSD_Card^MicroSD_Socket
Pin_CardIn^MicroSD_Socket
C_1206_3216Metric x 2
R_Array_Convex_4x0603 x 2
PinHeader_1x06_P2.54mm_Vertical
SOT-223
sdcard-adapter_PCB

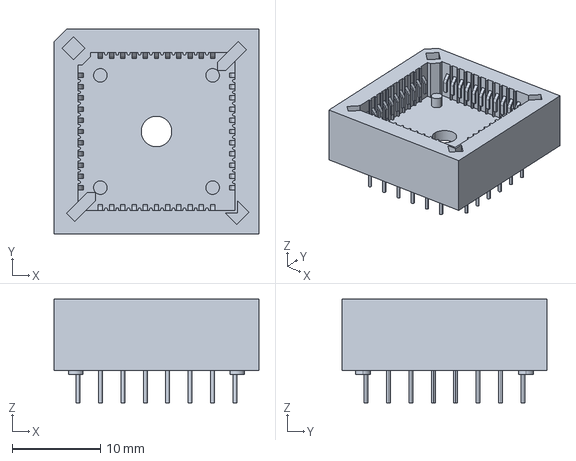
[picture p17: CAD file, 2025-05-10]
pcb/components/PLCC44_socket.stp
23.2 x 23.2 x 11.8 mm

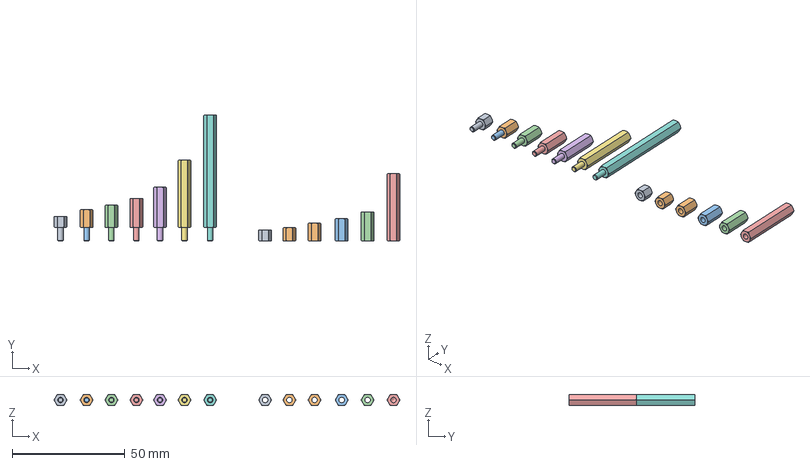
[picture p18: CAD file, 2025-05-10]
pcb/components/distans.stp
153.6 x 56.0 x 5.00 mm
OPT_DISTANSM3
DISTANSM3X10_VIDALI
DISTANSM3X10_VIDALI_1
DISTANSM3X10_VIDALI_2
DISTANSM3X18_VIDALI
DISTANSM3X30_VIDALI
DISTANSM3X50_VIDALI
DISTANSM3X5
DISTANSM3X10_VIDALI_3
DISTANSM3X10_VIDALI_4
DISTANSM3X10_VIDALI_5
DISTANSM3X10_VIDALI_6
DISTANSM3X30_DISI_DISI

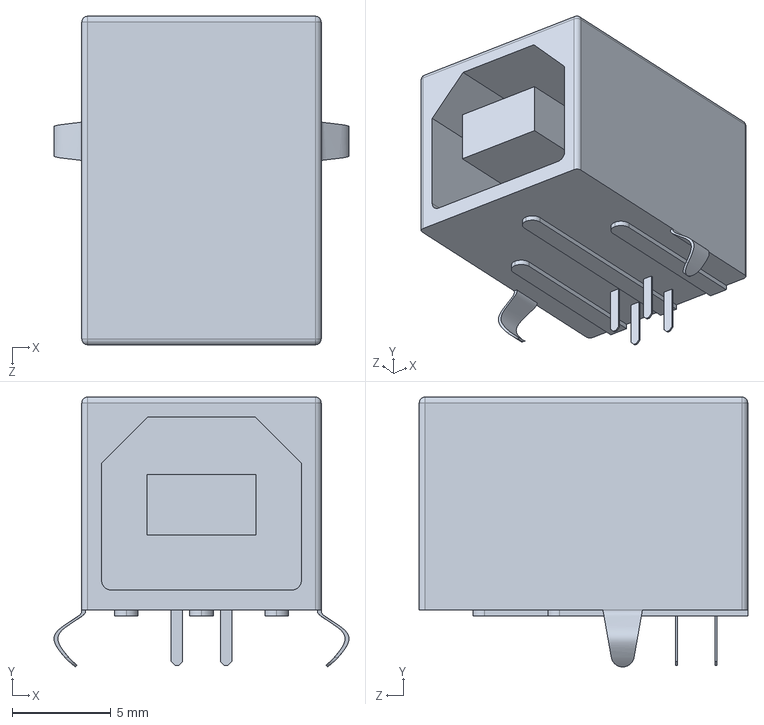
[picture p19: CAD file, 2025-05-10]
pcb/components/USB type-B female PCB.STEP
14.9 x 13.6 x 16.6 mm

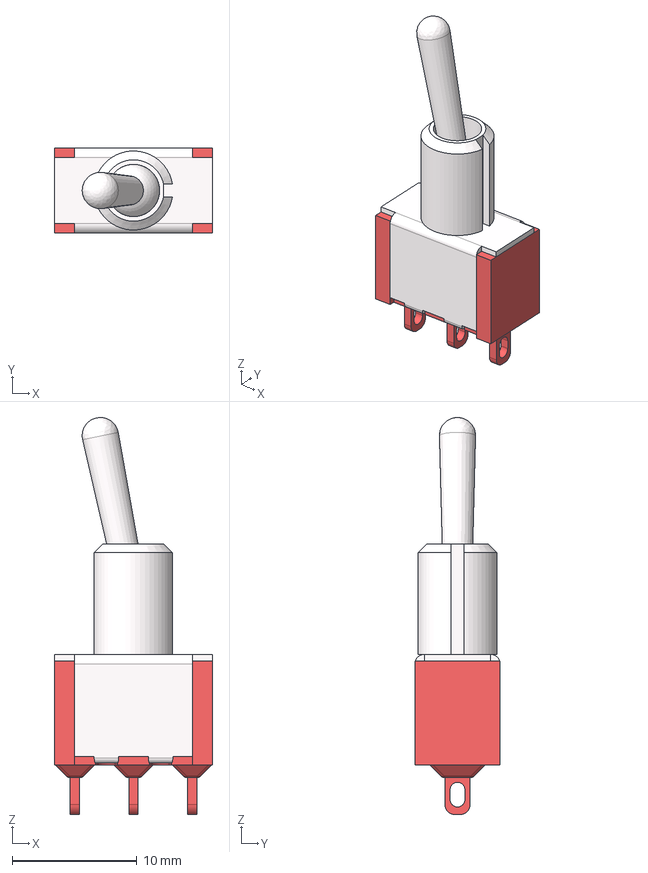
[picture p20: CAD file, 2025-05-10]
pcb/components/switch.stp
12.7 x 6.86 x 31.9 mm
100-300SPXBODY
100SPXBRACKET
100T1
100B1BUSHING
100-300SPXM1

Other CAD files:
baseplates/tinyboard/tinyboard_baseplate.stl

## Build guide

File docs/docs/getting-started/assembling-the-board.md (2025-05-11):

# Assembling the Board

## Soldering Components

When assembling the board, it's best to solder components in order of increasing height. This helps keep parts steady and ensures easier access during soldering. Follow the sequence below to make the process smooth and efficient.

### Tiny Board Assembly Guide

1. **Begin with the resistors**: Solder R1 through R6. These are flat and
   easiest to place first.

2. **Socket for CAN oscillator (X1)**: If you plan to socket the CAN oscillator,
   install its socket now before moving on.

3. **Install the DIP sockets**: Proceed with U1, U2, and U4 through U7. Note
   that U3 does not need a socket.  
   If your ceramic capacitors are taller than the DIP sockets, consider
   soldering the capacitors first (see next step) to avoid height conflicts.

4. **Add the ceramic capacitors**: Solder C1, C3, and C5 through C10. Also add
   C11.  
   Be careful with C12 — it should be a **30pF capacitor**, while the others are
   **100nF** and usually don’t have markings on the silkscreen.

5. **Place the DS1813 component**: This goes at U3 and should be inserted
   carefully.

6. **Install the tactile switches**: Mount SW2 and SW3. These are 6mm tall.

7. **Solder the LED**: Install the 5mm LED at D1, making sure the orientation is
   correct.

8. **Attach the pin header**: Solder the 2x20 male pin header at J2.

9. **Install the USB connector**: Solder the USB type B connector at J1.

10. **Add the serial connector**: Install the 9-pin SUBD serial port.

11. **Install the 10µF electrolytic capacitors**: Place C2 and C12 through C15.  
    Watch the polarity — these capacitors are polarized.

12. **Install the 100µF electrolytic capacitor**: Solder C4, also making sure to
    observe polarity.

13. **Place the oscillator**: Insert the 1.8432 MHz crystal oscillator at Y1.

14. **Finish with the toggle switch**: Finally, install SW1 — the tallest
    component — to complete the board.

Once all components are soldered, the only remaining task is to **insert the
chips into their sockets**. Be sure to align the chips correctly according to
the notch or dot marking on each IC and the corresponding silkscreen indicator
on the board.

## Flashing the ROM

Before powering up your ByteCradle board for the first time, it is essential to
flash the appropriate ROM image onto the onboard memory chip. The required ROM
chip and image depend on the variant of the board:

- **ByteCradle Tiny**: Uses an **SST39SF010** (1 Mbit) chip.
- **ByteCradle Mini**: Uses an **SST39SF040** (4 Mbit) chip.

Each board requires a specific ROM file that matches its hardware configuration.

### Required Tools

To flash the ROM, you'll need a compatible **EPROM/Flash programmer**. Options include:

- **Commercial Programmers**:
    * [TL866II Plus](https://www.autoelectric.cn/en/tl866_main.html): A popular, affordable universal programmer.
    * [XGecu T48](https://www.xgecu.com/EN/): A more advanced model supporting a wide range of devices.
- **Open Source and DIY Alternatives**:
    * [Pico-SST39SF0x0 Programmer](https://github.com/ifilot/pico-sst39sf0x0-programmer): A lightweight and affordable programmer using a Raspberry Pi Pico.
    * **Arduino-based Flashers**: Utilize an Arduino (e.g., Uno) with community firmware for programming simple parallel flash devices.

!!! note "Choosing a Flasher"
    Commercial programmers offer ready-to-use software and broad device support. However, open-source solutions like the Pico-SST39SF0x0 Programmer are cost-effective and excellent for DIY enthusiasts.

### Flashing Process Overview

1. **Set Up the Programmer**:
    - For the Pico-SST39SF0x0 Programmer:
    - Flash your Raspberry Pi Pico with the firmware from the [GitHub repository](https://github.com/ifilot/pico-sst39sf0x0-programmer).
    - Connect the ROM chip to the Pico according to the wiring guide provided in the repository.

2. **Load the ROM File**:
    - Open your flashing software.
    - Select the correct chip type from the supported devices list.
    - Load the appropriate ROM image for your ByteCradle board variant.

3. **Write and Verify**:
    - Erase the chip if necessary (some programmers do this automatically).
    - Write the ROM file to the flash chip.
    - Perform a verification pass to confirm the write was successful.

4. **Install the ROM**:
    - After successful flashing, insert the ROM chip carefully into its socket, **ensuring correct orientation**.

---

[:material-arrow-right: Next: Proceed to the first power up](first-power-up.md)

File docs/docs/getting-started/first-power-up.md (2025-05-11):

# First Power-Up and Testing

## Hooking up the Power Supply

The ByteCradle board requires a **5V power supply** capable of delivering at
least **500 mA** of current. Power is supplied through a **USB-B connector**.
The ByteCradle **does not** have any on-board power regulation. It is critical
to use a **reliable and regulated 5V power source** to avoid damaging the board.
Recommended options include:
    
- A direct connection to a **computer USB port**
- A **certified USB wall adapter** rated for 5V output

!!! warning "Power Supply Safety"    
    Avoid using low-quality or unregulated power adapters, as unstable voltages can cause erratic behavior or permanent damage to the board.

!!! note "Power-Up Sequence"
    Before powering up the board, make sure the **serial communication cable** (see next section) is connected and a **serial port** has been opened on your computer. This ensures you will see the header information that the board outputs upon boot. If you power on the board before setting up the serial connection, you can still communicate with it, but you will miss the initial startup messages. In that case, simply press the **reset button** on the board to perform a cold boot and re-trigger the startup sequence.

## Setting Up Serial Communication

Communication with the ByteCradle platform is handled via a **standard RS232
serial interface**, implemented using the onboard **65C51 ACIA** (Asynchronous
Communications Interface Adapter) and a **MAX232** line driver. This setup
ensures reliable and straightforward serial communication, supporting both TTL
and RS232 voltage levels.

The default communication settings are:

- **Baud Rate**: 115200
- **Data Bits**: 8
- **Parity**: None
- **Stop Bits**: 1

(commonly referred to as **8N1** configuration).

Several tools are available to interface with the board over RS232:

- **Windows**: [PuTTY](https://www.putty.org/), [Tera
  Term](https://osdn.net/projects/ttssh2/)
- **MacOS**: [CoolTerm](https://freeware.the-meiers.org/), or the built-in
  `screen` command
- **Linux**: [Minicom](https://help.ubuntu.com/community/Minicom), `screen`, or
  [picocom](https://linux.die.net/man/1/picocom)

!!! tip "Finding the correct serial port" 
    - **On Windows**: Open **Device
      Manager** and look under **Ports (COM & LPT)**. Your device will appear as
      something like `COM3`, `COM4`, etc. 
    - **On MacOS**: Use the command `ls
    /dev/tty.*` in Terminal. Look for entries like `/dev/tty.usbserial-XXXXX`. 
    - **On Linux**: Use `ls /dev/ttyUSB*` or `ls /dev/ttyACM*` depending on your
      USB-to-serial adapter. Common examples include `/dev/ttyUSB0`.

!!! note "Connection Tip" 
    After identifying the correct port, configure your
    terminal program with the settings above and open the connection. Upon
    powering up the ByteCradle, you should see output from the board if the
    connection is established correctly.

## Boot screen

If everything is working correctly, you should see the following boot screens
as shown below.

For the :material-chip: **TINY** board:

```
+----------------------------------------------+
| BYTECRADLE /TINY/ ROM                        |
+----------------------------------------------+
| RAM  : 0x0000 - 0x7EFF                       |
| ROM  : 0x8000 - 0xFFFF                       |
| IO   : 0x7F00 - 0x7FFF                       |
| ACIA : 0x7F04 - 0x7F0F                       |
+----------------------------------------------+
|     SELECT CATEGORY                          |
|                                              |
| (t) Test routines                            |
| (a) Applications                             |
| (g) Games                                    |
| (m) Monitor                                  |
+----------------------------------------------+
```

and for the :material-chip: **MINI** board:

```
 ____             __           ____                      __   ___
/\  _`\          /\ \__       /\  _`\                   /\ \ /\_ \
\ \ \L\ \  __  __\ \ ,_\    __\ \ \/\_\  _ __    __     \_\ \\//\ \      __
 \ \  _ <'/\ \/\ \\ \ \/  /'__`\ \ \/_/_/\`'__\/'__`\   /'_` \ \ \ \   /'__`\
  \ \ \L\ \ \ \_\ \\ \ \_/\  __/\ \ \L\ \ \ \//\ \L\.\_/\ \L\ \ \_\ \_/\  __/
   \ \____/\/`____ \\ \__\ \____\\ \____/\ \_\\ \__/.\_\ \___,_\/\____\ \____\
    \/___/  `/___/> \\/__/\/____/ \/___/  \/_/ \/__/\/_/\/__,_ /\/____/\/____/
               /\___/
               \/__/
  ____  ______     __      ___
 /'___\/\  ___\  /'__`\  /'___`\
/\ \__/\ \ \__/ /\ \/\ \/\_\ /\ \
\ \  _``\ \___``\ \ \ \ \/_/// /__
 \ \ \L\ \/\ \L\ \ \ \_\ \ // /_\ \
  \ \____/\ \____/\ \____//\______/
   \/___/  \/___/  \/___/ \/_____/

Starting system.
Clearing user space...   [OK]
Connecting to SD-card... [OK]
:/>
```

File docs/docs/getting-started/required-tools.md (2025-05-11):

# Required Tools

The tools you'll need depend on whether you're assembling the board yourself or
working with a pre-assembled unit.

## For Manual Assembly

If you're starting from a bare PCB and sourcing your own components, ensure you
have the following tools and equipment:

- **Soldering iron** — Preferably temperature-controlled for best results.
- **Solder** — Leaded solder is typically easier to work with, but choose
  according to your preference or safety requirements.
- **ROM flasher** — A reliable, advanced commercial flasher such as the **XGecu
  PRO**, which supports programming **Atmel SST39SF0X0** series chips.

### Board-Specific Requirements

- **For :material-chip: TINY boards**: A flasher that supports programming **ATF22V10** chips.
- **For :material-chip: MINI boards**: A flasher compatible with **ATF1502AS** chips.

## For Pre-Assembled Boards

If you're using a board that has already been assembled, your tool requirements
are simpler:

- A **SST39SF0X0-compatible flasher** — Many affordable and widely available
  flashers support this chip family.

!!! tip 
    While high-end flashers like the XGecu PRO are recommended for
    reliability, budget-friendly options may suffice for casual use, especially
    with pre-assembled boards. A budget-friendly option is the
    [PICO-SST39SF0x0-programmer](https://github.com/ifilot/pico-sst39sf0x0-programmer).

[:material-arrow-right: Next: Proceed to assembling the board](assembling-the-board.md)

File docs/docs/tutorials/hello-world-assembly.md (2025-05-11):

# Tutorial: Hello World in Assembly

This tutorial walks you through writing, building, and running a simple "Hello
World" program in 6502 assembly for the **ByteCradle OS**. The example uses the
`cc65` toolchain, a widely used suite for 6502-based development.

## Step 1: Writing the Assembly Code

Create a new file called `helloworld.asm` and enter the following code:

```assembly
;------------------------------------------------------------------------------
; Hello World Example for ByteCradle 6502
;
; This program prints "Hello World!" to the screen using the ByteCradle OS's
; built-in output routine located at $FFE8.
;------------------------------------------------------------------------------

.PSC02                              ; Assembly for the 65C02 CPU

.import __HEADER_LOAD__             ; Provided by the linker (.cfg) as load address

.define PUTSTRNL $FFE8              ; Routine to print a null-terminated string with newline

;------------------------------------------------------------------------------
; Program Header (used by ByteCradle OS to determine deployment address)
;------------------------------------------------------------------------------
.segment "HEADER"
.word __HEADER_LOAD__               ; Deployment address (typically $0800), little-endian

;------------------------------------------------------------------------------
; Main Code Segment
;------------------------------------------------------------------------------
.segment "CODE"

start:                              ; Entry point
    lda #<hwstr                     ; Load low byte of string address
    ldx #>hwstr                     ; Load high byte of string address
    jsr PUTSTRNL                    ; Call OS routine to print string with newline
    rts                             ; Return to OS

hwstr:
    .asciiz "Hello World!"          ; Null-terminated string
```

**How it works:**

* The program starts at the label start, which is called by the OS.
* It loads the address of a null-terminated string and calls 
  [the OS function](../software/kernel-functions.md) at
  `$FFE8`, which prints the string followed by a newline.
* The .segment "HEADER" section includes a 2-byte deployment address required by
  ByteCradle OS .COM files.
* The program ends with rts (return from subroutine), allowing the OS to regain
  control.

## Step 2: Writing the Makefile

Create a file called Makefile in the same directory:

```makefile
PROG = HELLO.COM
OBJ  = helloworld.o
CFG  = rom.cfg

all: $(PROG)

$(OBJ): helloworld.asm
	ca65 helloworld.asm -o $(OBJ)

$(PROG): $(OBJ)
	ld65 -o $(PROG) -C $(CFG) $(OBJ)
```    

This Makefile automates the build process:

* Assembles the source using `ca65`
* Links the program using `ld65` with a linker configuration file (`rom.cfg`)
* Produces an output file named `HELLO.COM`

## Step 3: Linker Configuration (rom.cfg)

You will also need a linker configuration file called `rom.cfg`. This tells the
linker how to place the code in memory:

```
MEMORY {
    HEADER: start = $0800, size = 2, file = %O;             # Explicit start position
    ROM:    start = $0802, size = $7FFE, file = %O;         # Start right after HEADER
}

SEGMENTS {
    HEADER: load = HEADER, type = ro, define = yes;
    CODE:   load = ROM, type = ro;
}
```

This layout matches the expectations of the ByteCradle OS, which reads the first
two bytes of a .COM file to determine where to load it into memory.

## Step 4: Building the Program

To compile and link your program, simply run:

```bash
make
```

This will produce a file called `HELLO.COM`, ready for deployment.

!!! note
    The resulting `HELLO.COM` file is only 23 bytes in size, very small. This
    is because the program basically only contains an instruction for a kernel
    function and nothing more.

## Step 5: Running the Program

Copy `HELLO.COM` to the SD card used by the ByteCradle system.

From the ByteCradle OS shell:

* Navigate to the folder containing the file using `cd`.
* Type the base name of the file (without the .COM extension):

```bash
hello
```

You should see:

```
Hello World!
```

!!! tip
    Instructions on how to deploy the program to your ByteCradle board are
    [provided here](../software/building-programs.md/#bytecradle-os)

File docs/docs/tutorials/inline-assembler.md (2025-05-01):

# Inline Assembler Tutorial

This section begins with a brief overview of the **monitor** and its role in the
system, followed by a tutorial on how to use its **inline assembler** feature to
build small, custom code snippets.

## Monitor

The **monitor** is a simple interactive program that gives you low-level control
over the system’s memory and CPU. It supports reading and writing memory,
executing code at arbitrary addresses, disassembling machine instructions, and
assembling new instructions directly from the command line using its built-in
assembler.

!!! note
    The description provided here pertains to the `/TINY/` board, but the
    instructions are transferable to the `/MINI/` board. The major difference
    is that the `/MINI/` board supports bank switching and has its ROM
    starting at `0xC000` where as the `/TINY/` has ROM starting at `0x8000`.

Upon booting the `/TINY/` board, you will be greeted with a selection menu
which allows you to select the `MONITOR` option. 

```
+----------------------------------------------+
|             BYTECRADLE MONITOR               |
+----------------------------------------------+
| FREE ZERO PAGE :     0x40 - 0xFF             |
| FREE RAM       : 0x0400 - 0x7F00             |
| ROM            : 0x8000 - 0xFFFF             |
+----------------------------------------------+
| COMMANDS                                     |
| R<XXXX>[:<XXXX>] read memory                 |
| W<XXXX>          write to memory             |
| G<XXXX>          run from address            |
| A<XXXX>          assemble from address       |
| D<XXXX>          disassemble from address    |
| M                show this menu              |
| Q                quit                        |
+----------------------------------------------+
```

## Monitor Functions

The Monitor provides several commands that allow direct interaction with the
system's memory and CPU. These functions are essential for writing, testing, and
debugging programs at a low level:

* Reading memory (`R<XXXX>[:<XXXX>]`) Allows you to examine memory contents at a
  specific address or within a range of addresses.
* Writing to memory (`W<XXXX>`) Enables manual modification of memory contents at
  a given address. Useful for inserting data like ASCII strings or instructions.
* Running code (`G<XXXX>`) Starts execution of code from a specific memory
  address, enabling you to run programs you have written or loaded into RAM.
* Inline assembly (`A<XXXX>`) Opens an assembler interface at the specified
  address, allowing you to input machine code instructions directly in mnemonic
  form.
* Disassembling code (`D<XXXX>`) Reads machine code from memory and converts it
  back into human-readable assembly instructions.
* Showing the menu (`M`) Displays the monitor’s command menu and current memory
  layout for quick reference.
* Quitting (`Q`) Exits the monitor and returns control to the system selection
  menu or operating environment.

These functions work together to provide a lightweight but powerful development
environment directly on the hardware.

## Sample programs

The following examples demonstrate how to use the Monitor’s inline assembler,
memory writing, and program execution features. By manually assembling
instructions and inserting data, you can create simple programs directly in
memory and run them without needing external tools. These exercises are ideal
for learning how the system interacts with memory and the CPU at a low level.

### Hello World

Open the inline-assembler using `A0400` and insert the following assembly instructions:

```ca65
0400: LDA #10       A9 10
0402: LDX #04       A2 04
0404: JSR FFE8      20 E8 FF
0407: RTS           60
```

Next, insert the ASCII characters for the string `Hello World!` by first typing `W0410` and entering the following values:

```
0410: 48 65 6C 6C 6F 20 57 6F 72 6C 64 21 00
```

To run the small program, type `G0400`.

The expected output is:

```
@:G0400
Hello World!
```

!!! note
    Observe that we used one of the kernel functions, `putch` located at `#FFE8`
    to output a single character to the ACIA. An overview of all the kernel
    functions can be found [here](../software/kernel-functions.md).

### Fibonacci series

Open the inline-assembler using `A0400` and insert the following assembly instructions:

```ca65
0400: LDA #01                  A9 01
0402: LDX #01                  A2 01
0404: LDY #00                  A0 00
0406: PHX                      DA
0407: PHY                      5A
0408: JSR FFF4                 20 F4 FF
040B: JSR FFEE                 20 EE FF
040E: PLY                      7A
040F: PLX                      FA
0410: STX 40                   86 40
0412: CLC                      18
0413: PHA                      48
0414: ADC 40                   65 40
0416: PLX                      FA
0417: INY                      C8
0418: CPY #0C                  C0 0C
041A: BNE EA                   D0 EA
041C: RTS                      60
```

!!!note
    The value of `$40` used for `STX 40` and `ADC 40` refer to zero page address
    `$40`. Note that we are only allowed to use zero page addresses starting from
    `$40` as everything below is used by the system (including the monitor).

To run the program, type `G0400`, which yields the following output:

```
@:G0400
1
2
3
5
8
13
21
34
55
89
```

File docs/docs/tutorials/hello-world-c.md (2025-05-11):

# Writing a Standalone C Program for ByteCradle with CC65

This tutorial walks through the process of building a standalone C program for
the **ByteCradle** platform using the **cc65 toolchain**. You'll learn how to
set up the startup code, write a simple `main()` function, configure memory
mapping, and compile the final binary.

!!! tip
    You can find several example programs in [the official repository](https://github.com/ifilot/bytecradle-6502/tree/master/programs).

## Prerequisites

- A Linux system with the `cc65` toolchain installed (`ca65`, `cc65`, `ld65`, `ar65`)
- Basic familiarity with 6502 architecture and C programming
- Make and a standard build environment

!!! tip
    More information on the toolchain is provided [here](../software/building-programs.md#toolchain).

## Project Structure

The project consists of the following files:

| File | Description |
|---|---|
| `crt0.s` | Startup code (called before `main()`) |
| `main.c` | Your main application in C |
| `io.h` | Helper for system-level I/O routines |
| `prog.cfg`  | Memory layout and segment configuration for the linker |
| `Makefile`  | Automates the build process |

## Step 1: Write the Startup Code

The startup assembly file initializes the stack, clears the BSS section, copies initialized data, and finally calls `main()`. It also defines an `_exit` routine for cleanup.

```
; ---------------------------------------------------------------------------
; crt0.s
; ---------------------------------------------------------------------------

.import __HEADER_LOAD__                     ; import start location

.export   _init, _exit
.import   _main, _charout

.export   __STARTUP__ : absolute = 1        ; Mark as startup
.import   __RAM_START__, __RAM_SIZE__       ; Linker generated

.import    copydata, zerobss, initlib, donelib

.include  "zeropage.inc"

; ---------------------------------------------------------------------------

.segment "HEADER"

.word __HEADER_LOAD__

; ---------------------------------------------------------------------------

.segment  "STARTUP"

; ---------------------------------------------------------------------------
; Set cc65 argument stack pointer
; ---------------------------------------------------------------------------
_init:

          LDA     #<(__RAM_START__ + __RAM_SIZE__)
          STA     sp
          LDA     #>(__RAM_START__ + __RAM_SIZE__)
          STA     sp+1

; ---------------------------------------------------------------------------
; Initialize memory storage
; ---------------------------------------------------------------------------

          JSR     zerobss              ; Clear BSS segment
          JSR     copydata             ; Initialize DATA segment
          JSR     initlib              ; Run constructors

; ---------------------------------------------------------------------------
; Call main()
; ---------------------------------------------------------------------------

          JSR     _main

; ---------------------------------------------------------------------------
; Back from main (this is also the _exit entry):  force a software break
; ---------------------------------------------------------------------------

_exit:    JSR     donelib              ; Run destructors
          RTS
```

## Step 2: Create I/O Header

This header declares a function pointer to the system's ROM-based string printing routine at address `$FFE8`. This lets us call system functions from C.

```c
#ifndef _IO_H
#define _IO_H

#include <stdint.h>

// ByteCradle OS: Print null-terminated string with newline (ROM $FFE8)
void (*putstrnl)(const uint8_t*) = (void (*)(const uint8_t*))0xFFE8;

#endif // _IO_H
```

## Step 3: Write the Main C Program

This is a simple "Hello World" program that prints to the screen using `putstrnl`.

```c
#include "io.h"

int main() {
    putstrnl("Hello World!");
    return 0;
}
```

## Step 4: Configure Memory Layout

The linker configuration (`prog.cfg`) defines where various sections of the program go in memory, including a 2-byte header, zero page usage, and stack space.

```
MEMORY {
    ZP:     start = $50, size = $B0, type = rw, define = yes;
    HEADER: start = $0800, size = 2, file = %O;
    RAM:    start = $0802, size = $7700-$0802, type = rw, define = yes;
    STACK:  start = $7700, size = $0800, type = rw, define = yes;
}

SEGMENTS {
    ZEROPAGE: load = ZP,        type = zp,  define   = yes;
    HEADER:   load = HEADER,    type = ro,  define   = yes;
    STARTUP:  load = RAM,       type = ro;
    CODE:     load = RAM,       type = ro;
    ONCE:     load = RAM,       type = ro,  optional = yes;
    RODATA:   load = RAM,       type = ro;
    DATA:     load = RAM,       type = rw,  define   = yes, run = RAM;
    BSS:      load = RAM,       type = bss, define   = yes;
    HEAP:     load = RAM,       type = bss, optional = yes;
}

FEATURES {
    CONDES:    segment = STARTUP,
               type    = constructor,
               label   = __CONSTRUCTOR_TABLE__,
               count   = __CONSTRUCTOR_COUNT__;
    CONDES:    segment = STARTUP,
               type    = destructor,
               label   = __DESTRUCTOR_TABLE__,
               count   = __DESTRUCTOR_COUNT__;
}

SYMBOLS {
    # Define the stack size for the application
    __STACKSIZE__:  value = $0200, type = weak;
}
```

## Step 5: Create the Makefile

The `Makefile` automates the build by assembling and linking your C and assembly
files into a `.COM` binary that can be run on ByteCradle.

```makefile
PROG = HELLOC.COM

all: $(PROG)

$(PROG): prog.cfg crt0.o main.o prog.lib
	ar65 a prog.lib crt0.o
	ld65 -C prog.cfg -m main.map main.o -o $(PROG) prog.lib

crt0.o: crt0.s
	ca65 --cpu 65c02 crt0.s

main.s: main.c
	cc65 -t none -O --cpu 65c02 main.c

prog.lib: crt0.o
	cp -v /usr/share/cc65/lib/supervision.lib prog.lib 
	ar65 a prog.lib crt0.o

main.o: main.s
	ca65 --cpu 65c02 main.s

clean:
	rm -v *.o *.lib main.s $(PROG)
```

## Step 6: Build the Program

From the terminal, run:

```bash
make
```

## Step 7: Run the program

Copy the resulting HELLOC.COM file to the ByteCradle's SD card or upload it
using the appropriate method. Then, on the ByteCradle shell:

```
:/> helloc
Hello World!
:/>
```

!!! tip 
    Instructions on how to deploy the program to your ByteCradle board,
    including for the TinyROM which does not have an SD-CARD, are [provided
    here](../software/building-programs.md/#bytecradle-os)

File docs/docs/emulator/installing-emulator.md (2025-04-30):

# Installing and Running the Emulator

This guide explains how to compile and run the `bc6502emu` emulator on a modern
POSIX-compatible system. The emulator supports both the `tiny` and `mini`
variants of the ByteCradle 6502 board and is designed for fast and simple
command-line usage.

## Platform Requirements

We assume you are working in a [POSIX](https://en.wikipedia.org/wiki/POSIX) environment, such as Linux or macOS.  
For Windows users, we warmly recommend installing 
[Windows Subsystem for Linux (WSL)](https://learn.microsoft.com/en-us/windows/wsl/).
All development and testing have been done using Ubuntu, and we recommend it as the reference environment.

## Prerequisites

Before you begin, make sure your system meets the following requirements:

- A C++17-compatible compiler
- [CMake](https://cmake.org/) for managing the build process
- The [TCLAP](https://tclap.sourceforge.net/) library for command-line parsing

To install all required dependencies on Ubuntu or Debian-based systems, run:

```bash
sudo apt update && sudo apt install build-essential cmake libtclap-dev
```

After compilation, the emulator binary will be located in the `build` directory
under the name `bc6502emu`.

!!! tip "Ready to start using the emulator?"
    Go to the [Running the Emulator](./running-emulator.md)

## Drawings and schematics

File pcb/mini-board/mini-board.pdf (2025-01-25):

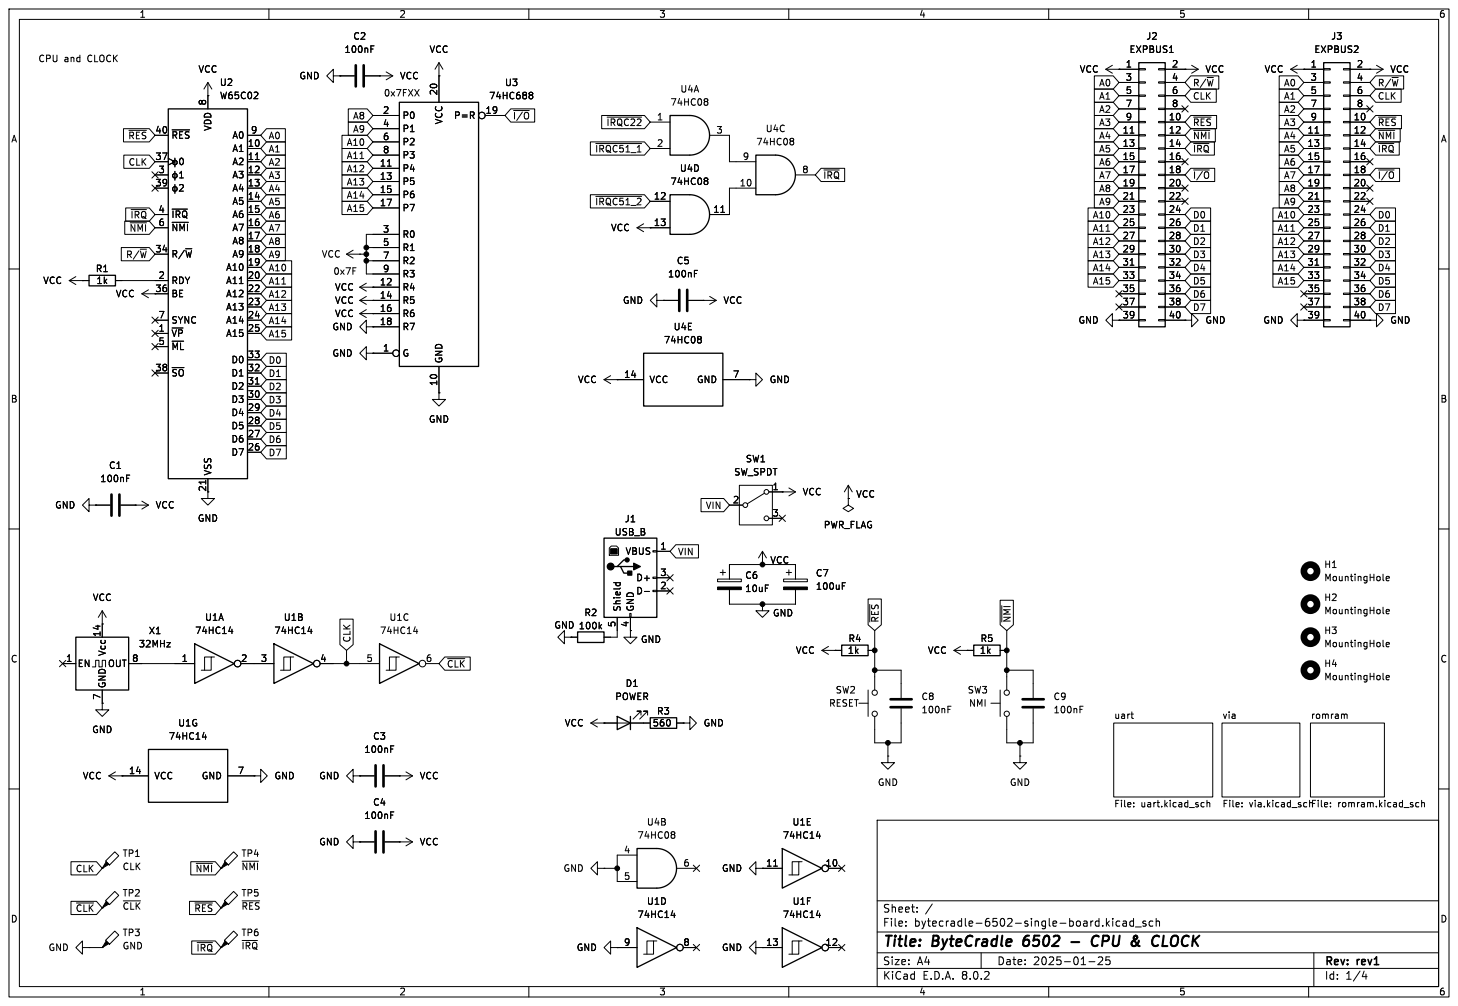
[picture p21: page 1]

Id: 1/4 Title: ByteCradle 6502 - CPU & CLOCK

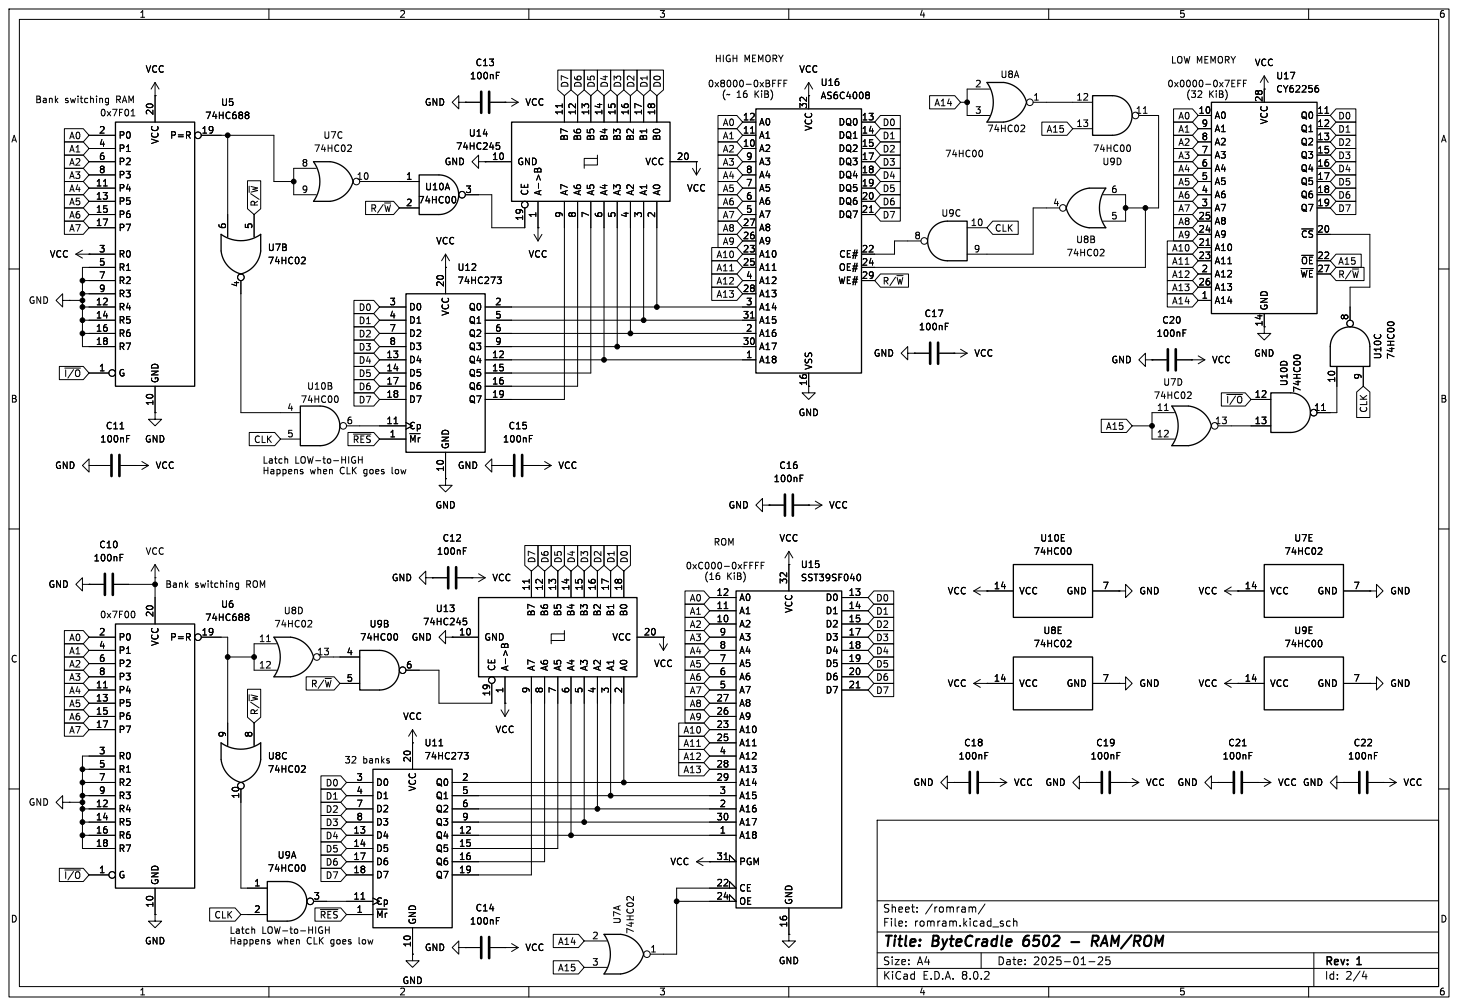
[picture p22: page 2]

Latch LOW-to-HIGH
Happens when CLK goes low

Id: 2/4 Title: ByteCradle 6502 - RAM/ROM

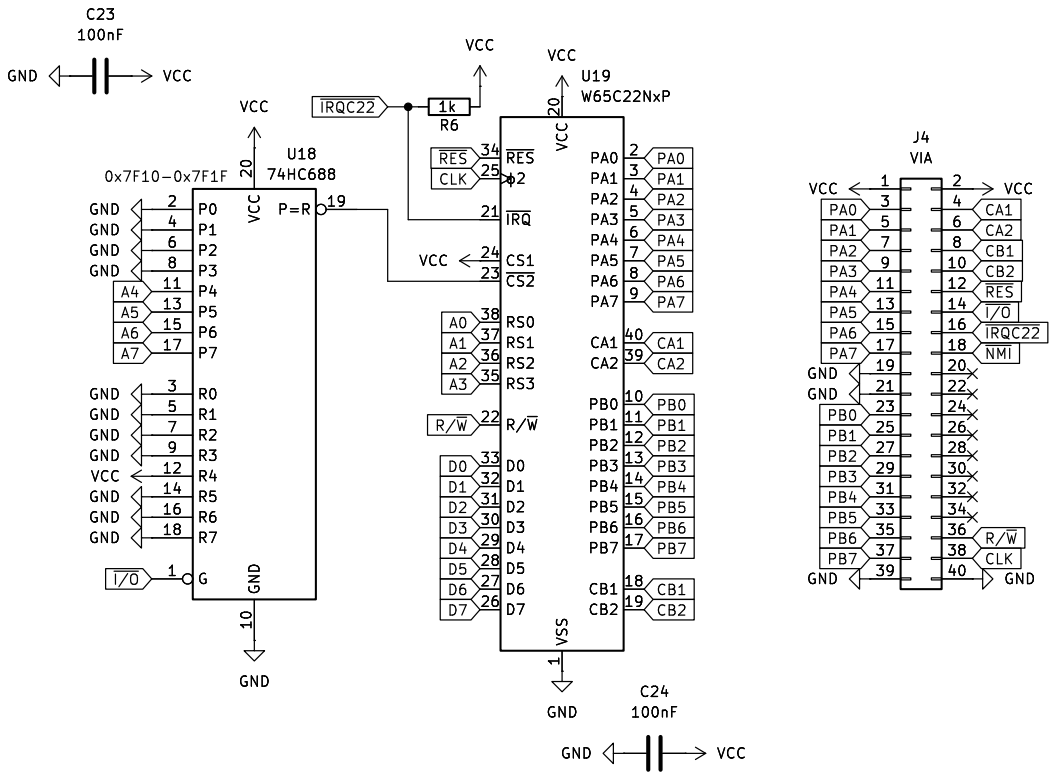
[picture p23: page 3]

Id: 3/4 Title: ByteCradle 6502 - Versatile Interface Adapter File: via.kicad_sch Sheet: /via/

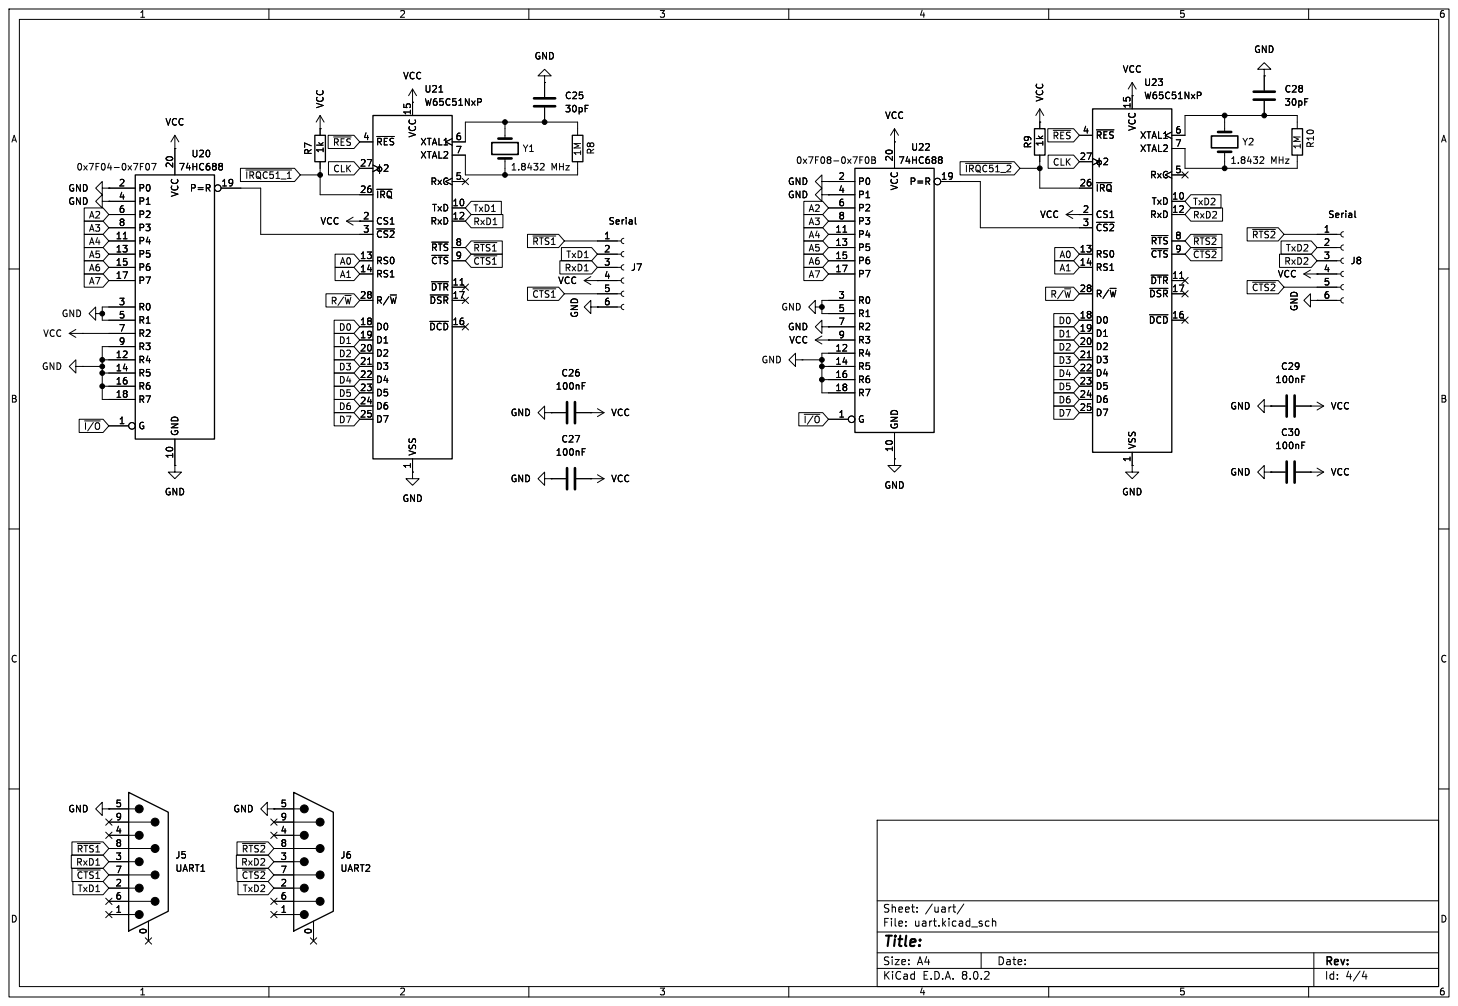
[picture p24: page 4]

1 TxD 10 ~{DTR} 11 RxD 12 RS0 13 RS1 14 VCC 15

VCC GND GND GND

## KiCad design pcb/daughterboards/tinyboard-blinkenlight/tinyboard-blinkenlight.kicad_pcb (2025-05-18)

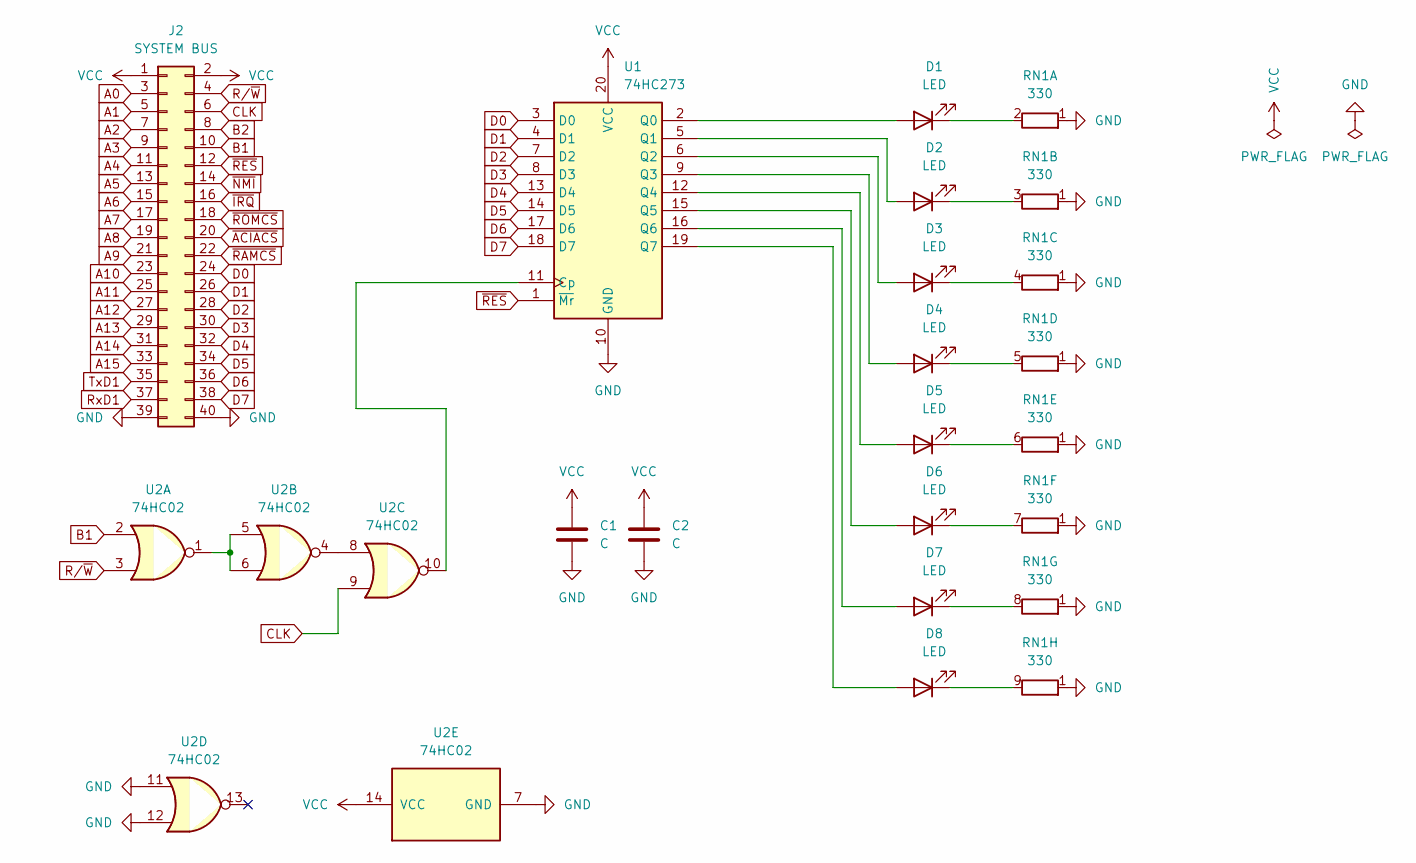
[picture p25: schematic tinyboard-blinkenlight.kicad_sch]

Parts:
C1, C2: C; C_Disc_D5.0mm_W2.5mm_P5.00mm
D1, D2, D3, D4, D5, D6, D7, D8: LED; LED_D5.0mm
J2: SYSTEM BUS; PinSocket_2x20_P2.54mm_Vertical
RN1: 330; R_Array_SIP9
U1: 74HC273; DIP-20_W7.62mm_Socket
U2: 74HC02; DIP-14_W7.62mm_Socket

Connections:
A0: J2.3
A1: J2.5
A2: J2.7
A3: J2.9
A4: J2.11
A5: J2.13
A6: J2.15
A7: J2.17
A8: J2.19
A9: J2.21
A10: J2.23
A11: J2.25
A12: J2.27
A13: J2.29
A14: J2.31
A15: J2.33
B1: J2.10, U2.2
B2: J2.8
CLK: J2.6, U2.9
D0: J2.24, U1.3 (D0)
D1: J2.26, U1.4 (D1)
D2: J2.28, U1.7 (D2)
D3: J2.30, U1.8 (D3)
D4: J2.32, U1.13 (D4)
D5: J2.34, U1.14 (D5)
D6: J2.36, U1.17 (D6)
D7: J2.38, U1.18 (D7)
GND: C1.2, C2.2, J2.39, J2.40, RN1.1 (R1), U1.10 (GND), U2.7 (GND), U2.11, U2.12
unnamed: D1.2 (A), U1.2 (Q0)
unnamed: D1.1 (K), RN1.2 (R1.2)
unnamed: D2.2 (A), U1.5 (Q1)
unnamed: D2.1 (K), RN1.3 (R2.2)
unnamed: D3.2 (A), U1.6 (Q2)
unnamed: D3.1 (K), RN1.4 (R3.2)
unnamed: D4.2 (A), U1.9 (Q3)
unnamed: D4.1 (K), RN1.5 (R4.2)
unnamed: D5.2 (A), U1.12 (Q4)
unnamed: D5.1 (K), RN1.6 (R5.2)
unnamed: D6.2 (A), U1.15 (Q5)
unnamed: D6.1 (K), RN1.7 (R6.2)
unnamed: D7.2 (A), U1.16 (Q6)
unnamed: D7.1 (K), RN1.8 (R7.2)
unnamed: D8.2 (A), U1.19 (Q7)
unnamed: D8.1 (K), RN1.9 (R8.2)
unnamed: U1.11 (Cp), U2.10
unnamed: U2.1, U2.5, U2.6
unnamed: U2.4, U2.8
RxD1: J2.37
R/~W: J2.4, U2.3
TxD1: J2.35
VCC: C1.1, C2.1, J2.1, J2.2, U1.20 (VCC), U2.14 (VCC)
~ACIACS: J2.20
~IRQ: J2.16
~NMI: J2.14
~RAMCS: J2.22
~RES: J2.12, U1.1 (~Mr)
~ROMCS: J2.18

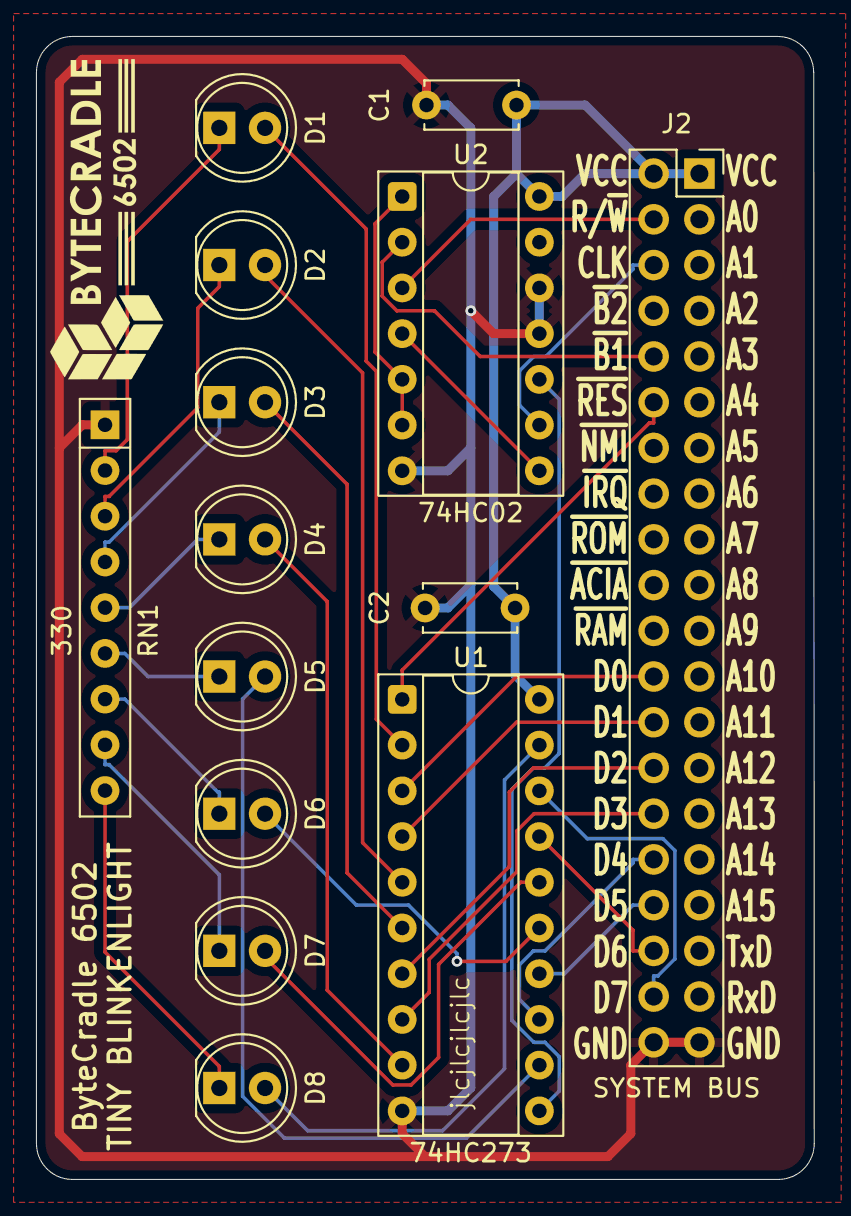
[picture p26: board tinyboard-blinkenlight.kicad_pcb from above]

Board: 2 copper layers, 43.2 x 63.5 mm, 14 parts (0 on the bottom side), 33 nets.

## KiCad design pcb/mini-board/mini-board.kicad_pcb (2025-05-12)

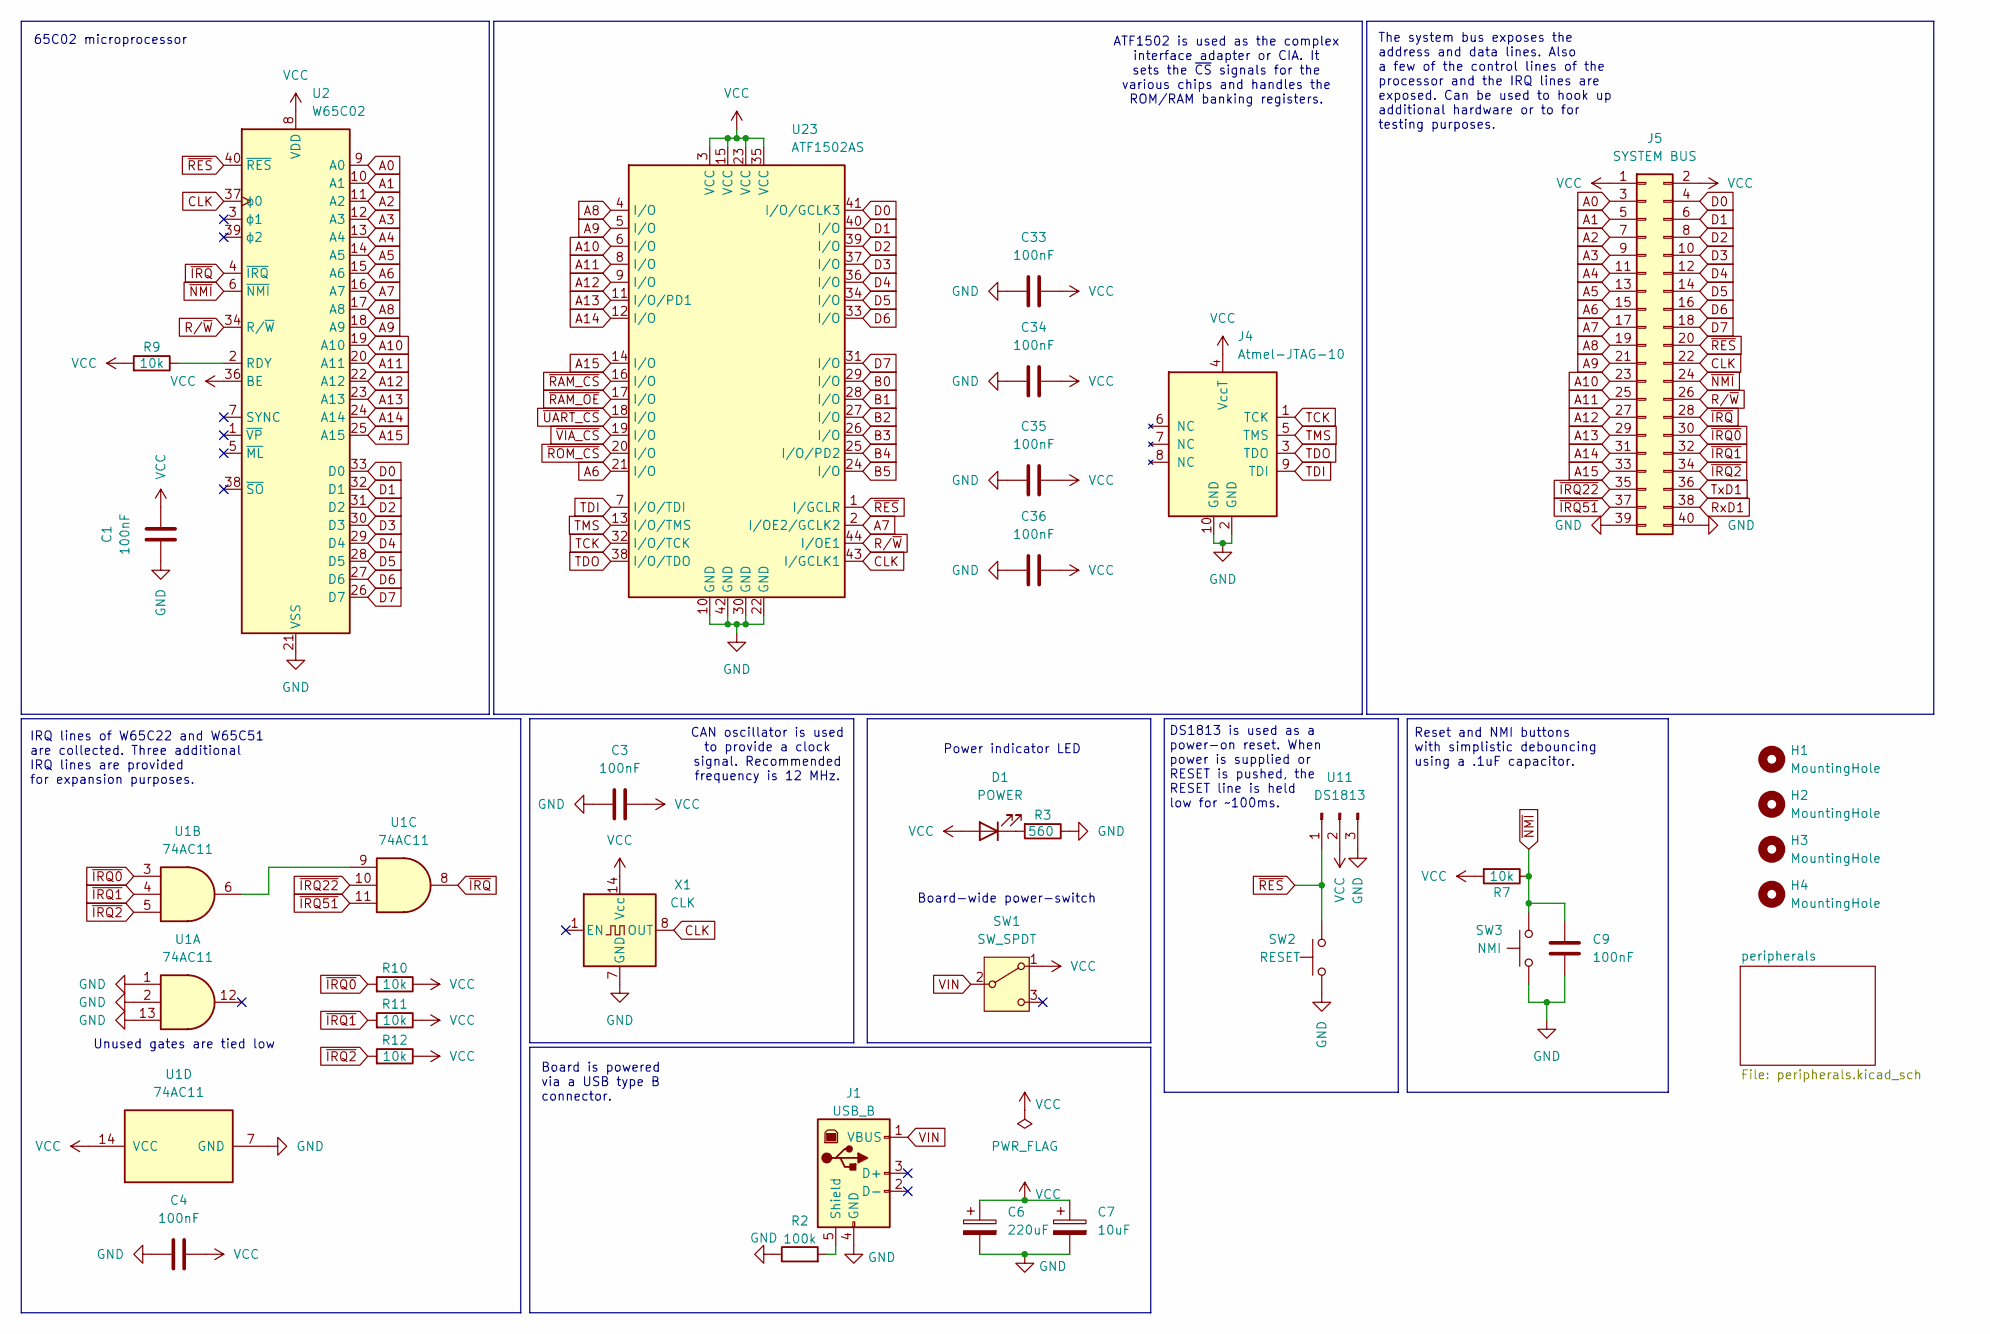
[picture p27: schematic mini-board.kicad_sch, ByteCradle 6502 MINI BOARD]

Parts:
C1, C3, C4, C9, C33, C34, C35, C36: 100nF; C_Disc_D5.0mm_W2.5mm_P5.00mm
C6: 220uF; CP_Radial_D6.3mm_P2.50mm
C7: 10uF; CP_Radial_D5.0mm_P2.50mm
D1: POWER; LED_D5.0mm
H1, H2, H3, H4: MountingHole; MountingHole_3.2mm_M3_DIN965_Pad_TopOnly
J1: USB_B; USB_B_OST_USB-B1HSxx_Horizontal
J4: Atmel-JTAG-10; IDC-Header_2x05_P2.54mm_Vertical
J5: SYSTEM BUS; PinHeader_2x20_P2.54mm_Vertical
R2: 100k; R_Axial_DIN0207_L6.3mm_D2.5mm_P7.62mm_Horizontal
R3: 560; R_Axial_DIN0207_L6.3mm_D2.5mm_P7.62mm_Horizontal
R7, R9, R10, R11, R12: 10k; R_Axial_DIN0207_L6.3mm_D2.5mm_P7.62mm_Horizontal
SW1: SW_SPDT; power_switch
SW2: RESET; SW_PUSH_6mm
SW3: NMI; SW_PUSH_6mm
U1: 74AC11; DIP-14_W7.62mm_Socket
U2: W65C02; DIP-40_W15.24mm_Socket
U11: DS1813; TO-92
U23: ATF1502AS; PLCC-44_THT-Socket
X1: CLK; Oscillator_DIP-14

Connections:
A0: J5.3, U2.9 (A0); also elsewhere on the board
A1: J5.5, U2.10 (A1); also elsewhere on the board
A2: J5.7, U2.11 (A2); also elsewhere on the board
A3: J5.9, U2.12 (A3); also elsewhere on the board
A4: J5.11, U2.13 (A4); also elsewhere on the board
A5: J5.13, U2.14 (A5); also elsewhere on the board
A6: J5.15, U2.15 (A6), U23.21 (I/O); also elsewhere on the board
A7: J5.17, U2.16 (A7), U23.2 (I/OE2/GCLK2); also elsewhere on the board
A8: J5.19, U2.17 (A8), U23.4 (I/O); also elsewhere on the board
A9: J5.21, U2.18 (A9), U23.5 (I/O); also elsewhere on the board
A10: J5.23, U2.19 (A10), U23.6 (I/O); also elsewhere on the board
A11: J5.25, U2.20 (A11), U23.8 (I/O); also elsewhere on the board
A12: J5.27, U2.22 (A12), U23.9 (I/O); also elsewhere on the board
A13: J5.29, U2.23 (A13), U23.11 (I/O/PD1)
A14: J5.31, U2.24 (A14), U23.12 (I/O)
A15: J5.33, U2.25 (A15), U23.14 (I/O)
B0: U23.29 (I/O); also elsewhere on the board
B1: U23.28 (I/O); also elsewhere on the board
B2: U23.27 (I/O); also elsewhere on the board
B3: U23.26 (I/O); also elsewhere on the board
B4: U23.25 (I/O/PD2); also elsewhere on the board
B5: U23.24 (I/O); also elsewhere on the board
CLK: J5.22, U2.37 (ϕ0), U23.43 (I/GCLK1), X1.8 (OUT); also elsewhere on the board
D0: J5.4, U2.33 (D0), U23.41 (I/O/GCLK3); also elsewhere on the board
D1: J5.6, U2.32 (D1), U23.40 (I/O); also elsewhere on the board
D2: J5.8, U2.31 (D2), U23.39 (I/O); also elsewhere on the board
D3: J5.10, U2.30 (D3), U23.37 (I/O); also elsewhere on the board
D4: J5.12, U2.29 (D4), U23.36 (I/O); also elsewhere on the board
D5: J5.14, U2.28 (D5), U23.34 (I/O); also elsewhere on the board
D6: J5.16, U2.27 (D6), U23.33 (I/O); also elsewhere on the board
D7: J5.18, U2.26 (D7), U23.31 (I/O); also elsewhere on the board
GND: C1.2, C3.2, C4.2, C6.2, C7.2, C9.2, C33.2, C34.2, C35.2, C36.2, J1.4 (GND), J4.2 (GND), J4.10 (GND), J5.39, J5.40, R2.1, R3.1, SW2.1, SW3.1, U1.1, U1.2, U1.7 (GND), U1.13, U2.21 (VSS), U11.3, U23.10 (GND), U23.22 (GND), U23.30 (GND), U23.42 (GND), X1.7 (GND); also elsewhere on the board
unnamed: D1.1 (K), R3.2
unnamed: J1.5 (Shield), R2.2
unnamed: U1.6, U1.9
unnamed: R9.1, U2.2 (RDY)
RxD1: J5.38; also elsewhere on the board
R/~W: J5.26, U2.34 (R/~W), U23.44 (I/OE1); also elsewhere on the board
TCK: J4.1 (TCK), U23.32 (I/O/TCK)
TDI: J4.9 (TDI), U23.7 (I/O/TDI)
TDO: J4.3 (TDO), U23.38 (I/O/TDO)
TMS: J4.5 (TMS), U23.13 (I/O/TMS)
TxD1: J5.36; also elsewhere on the board
VCC: C1.1, C3.1, C4.1, C6.1, C7.1, C33.1, C34.1, C35.1, C36.1, D1.2 (A), J4.4 (VccT), J5.1, J5.2, R7.2, R9.2, R10.1, R11.1, R12.1, SW1.1 (A), U1.14 (VCC), U2.8 (VDD), U2.36 (BE), U11.2, U23.3 (VCC), U23.15 (VCC), U23.23 (VCC), U23.35 (VCC), X1.14 (Vcc); also elsewhere on the board
VIN: J1.1 (VBUS), SW1.2 (B)
~IRQ0: J5.30, R10.2, U1.3
~IRQ1: J5.32, R11.2, U1.4
~IRQ2: J5.34, R12.2, U1.5
~IRQ22: J5.35, U1.10; also elsewhere on the board
~IRQ51: J5.37, U1.11; also elsewhere on the board
~IRQ: J5.28, U1.8, U2.4 (~IRQ)
~NMI: C9.1, J5.24, R7.1, SW3.2, U2.6 (~NMI); also elsewhere on the board
~RAM_CS: U23.16 (I/O); also elsewhere on the board
~RAM_OE: U23.17 (I/O); also elsewhere on the board
~RES: J5.20, SW2.2, U2.40 (~RES), U11.1, U23.1 (I/GCLR); also elsewhere on the board
~ROM_CS: U23.20 (I/O); also elsewhere on the board
~UART_CS: U23.18 (I/O); also elsewhere on the board
~VIA_CS: U23.19 (I/O); also elsewhere on the board

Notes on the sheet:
ATF1502 is used as the complex interface adapter or CIA. It sets the ~{CS} signals for the various chips and handles the ROM/RAM banking registers.
DS1813 is used as a power-on reset. When power is supplied or RESET is pushed, the RESET line is held low for ~100ms.
65C02 microprocessor
IRQ lines of W65C22 and W65C51 are collected. Three additional IRQ lines are provided for expansion purposes.
Reset and NMI buttons with simplistic debouncing using a .1uF capacitor.
Power indicator LED
The system bus exposes the address and data lines. Also a few of the control lines of the processor and the IRQ lines are exposed. Can be used to hook up additional hardware or to for testing purposes.
Unused gates are tied low
CAN oscillator is used to provide a clock signal. Recommended frequency is 12 MHz.
Board is powered via a USB type B connector.
Board-wide power-switch

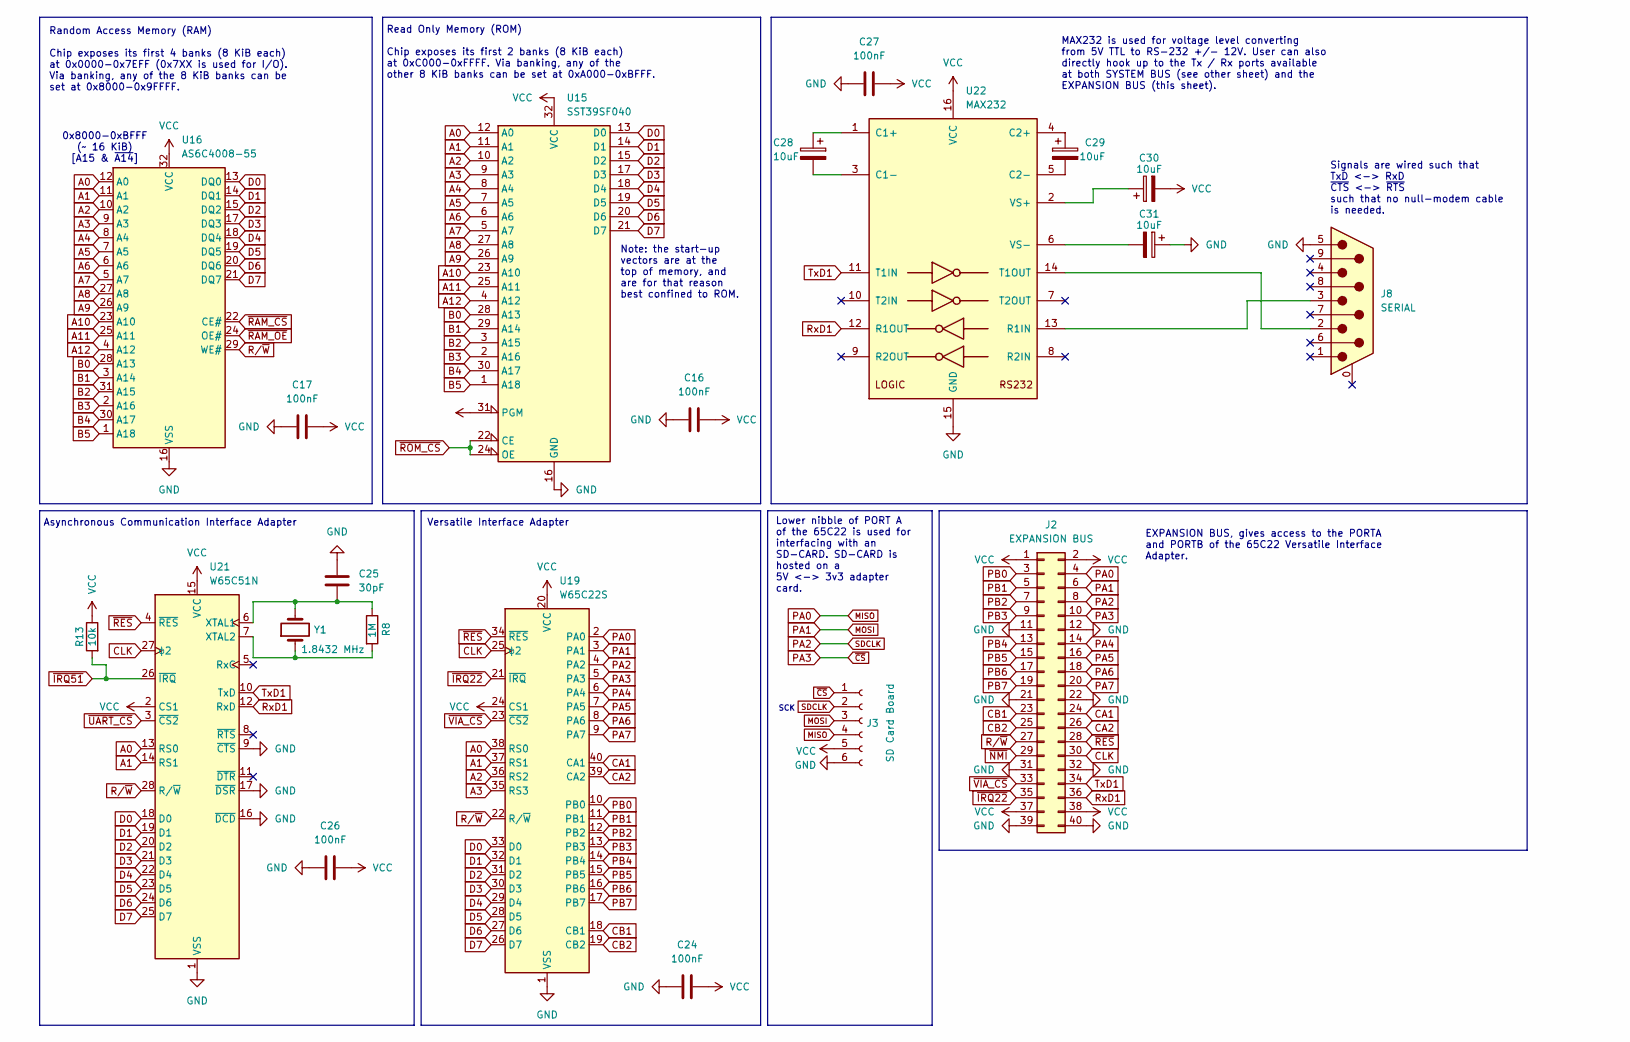
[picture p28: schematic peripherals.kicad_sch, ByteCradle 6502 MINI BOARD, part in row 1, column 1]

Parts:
C16, C17, C24, C26, C27: 100nF; C_Disc_D5.0mm_W2.5mm_P5.00mm
C25: 30pF; C_Disc_D5.0mm_W2.5mm_P5.00mm
C28, C29, C30, C31: 10uF; CP_Radial_D5.0mm_P2.50mm
J2: EXPANSION BUS; PinHeader_2x20_P2.54mm_Vertical
J3: SD Card Board; sdcard-socket
J8: SERIAL; DSUB-9_Pins_Horizontal_P2.77x2.84mm_EdgePinOffset4.94mm_Hou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
R8: 1M; R_Axial_DIN0207_L6.3mm_D2.5mm_P7.62mm_Horizontal
R13: 10k; R_Axial_DIN0207_L6.3mm_D2.5mm_P7.62mm_Horizontal
U15: SST39SF040; DIP-32_W15.24mm_Socket
U16: AS6C4008-55; DIP-32_W15.24mm_Socket
U19: W65C22S; DIP-40_W15.24mm_Socket
U21: W65C51N; DIP-28_W15.24mm_Socket
U22: MAX232; DIP-16_W7.62mm_Socket
Y1: 1.8432 MHz; Crystal_HC50_Vertical

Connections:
A0: U15.12 (A0), U16.12 (A0), U19.38 (RS0), U21.13 (RS0); also elsewhere on the board
A1: U15.11 (A1), U16.11 (A1), U19.37 (RS1), U21.14 (RS1); also elsewhere on the board
A2: U15.10 (A2), U16.10 (A2), U19.36 (RS2); also elsewhere on the board
A3: U15.9 (A3), U16.9 (A3), U19.35 (RS3); also elsewhere on the board
A4: U15.8 (A4), U16.8 (A4); also elsewhere on the board
A5: U15.7 (A5), U16.7 (A5); also elsewhere on the board
A6: U15.6 (A6), U16.6 (A6); also elsewhere on the board
A7: U15.5 (A7), U16.5 (A7); also elsewhere on the board
A8: U15.27 (A8), U16.27 (A8); also elsewhere on the board
A9: U15.26 (A9), U16.26 (A9); also elsewhere on the board
A10: U15.23 (A10), U16.23 (A10); also elsewhere on the board
A11: U15.25 (A11), U16.25 (A11); also elsewhere on the board
A12: U15.4 (A12), U16.4 (A12); also elsewhere on the board
B0: U15.28 (A13), U16.28 (A13); also elsewhere on the board
B1: U15.29 (A14), U16.3 (A14); also elsewhere on the board
B2: U15.3 (A15), U16.31 (A15); also elsewhere on the board
B3: U15.2 (A16), U16.2 (A16); also elsewhere on the board
B4: U15.30 (A17), U16.30 (A17); also elsewhere on the board
B5: U15.1 (A18), U16.1 (A18); also elsewhere on the board
CA1: J2.24, U19.40 (CA1)
CA2: J2.26, U19.39 (CA2)
CB1: J2.23, U19.18 (CB1)
CB2: J2.25, U19.19 (CB2)
CLK: J2.30, U19.25 (ϕ2), U21.27 (ϕ2); also elsewhere on the board
D0: U15.13 (D0), U16.13 (DQ0), U19.33 (D0), U21.18 (D0); also elsewhere on the board
D1: U15.14 (D1), U16.14 (DQ1), U19.32 (D1), U21.19 (D1); also elsewhere on the board
D2: U15.15 (D2), U16.15 (DQ2), U19.31 (D2), U21.20 (D2); also elsewhere on the board
D3: U15.17 (D3), U16.17 (DQ3), U19.30 (D3), U21.21 (D3); also elsewhere on the board
D4: U15.18 (D4), U16.18 (DQ4), U19.29 (D4), U21.22 (D4); also elsewhere on the board
D5: U15.19 (D5), U16.19 (DQ5), U19.28 (D5), U21.23 (D5); also elsewhere on the board
D6: U15.20 (D6), U16.20 (DQ6), U19.27 (D6), U21.24 (D6); also elsewhere on the board
D7: U15.21 (D7), U16.21 (DQ7), U19.26 (D7), U21.25 (D7); also elsewhere on the board
GND: C16.2, C17.2, C24.2, C25.1, C26.2, C27.2, C31.1, J2.11, J2.12, J2.21, J2.22, J2.31, J2.32, J2.39, J2.40, J3.6, J8.5, U15.16 (GND), U16.16 (VSS), U19.1 (VSS), U21.1 (VSS), U21.9 (~CTS), U21.16 (~DCD), U21.17 (~DSR), U22.15 (GND); also elsewhere on the board
MISO: J2.4, J3.4, U19.2 (PA0)
MOSI: J2.6, J3.3, U19.3 (PA1)
unnamed: C25.2, R8.1, U21.6 (XTAL1), Y1.2
unnamed: R8.2, U21.7 (XTAL2), Y1.1
unnamed: C28.1, U22.1 (C1+)
unnamed: C28.2, U22.3 (C1-)
unnamed: C29.1, U22.4 (C2+)
unnamed: C29.2, U22.5 (C2-)
unnamed: J8.3, U22.13 (R1IN)
unnamed: J8.2, U22.14 (T1OUT)
unnamed: C30.1, U22.2 (VS+)
unnamed: C31.2, U22.6 (VS-)
PA2: J2.8, J3.2, U19.4 (PA2)
PA3: J2.10, J3.1, U19.5 (PA3)
PA4: J2.14, U19.6 (PA4)
PA5: J2.16, U19.7 (PA5)
PA6: J2.18, U19.8 (PA6)
PA7: J2.20, U19.9 (PA7)
PB0: J2.3, U19.10 (PB0)
PB1: J2.5, U19.11 (PB1)
PB2: J2.7, U19.12 (PB2)
PB3: J2.9, U19.13 (PB3)
PB4: J2.13, U19.14 (PB4)
PB5: J2.15, U19.15 (PB5)
PB6: J2.17, U19.16 (PB6)
PB7: J2.19, U19.17 (PB7)
RxD1: J2.36, U21.12 (RxD), U22.12 (R1OUT); also elsewhere on the board
R/~W: J2.27, U16.29 (WE#), U19.22 (R/~W), U21.28 (R/~W); also elsewhere on the board
TxD1: J2.34, U21.10 (TxD), U22.11 (T1IN); also elsewhere on the board
VCC: C16.1, C17.1, C24.1, C26.1, C27.1, C30.2, J2.1, J2.2, J2.37, J2.38, J3.5, R13.1, U15.31 (PGM), U15.32 (VCC), U16.32 (VCC), U19.20 (VCC), U19.24 (CS1), U21.2 (CS1), U21.15 (VCC), U22.16 (VCC); also elsewhere on the board
~IRQ22: J2.35, U19.21 (~IRQ); also elsewhere on the board
~IRQ51: R13.2, U21.26 (~IRQ); also elsewhere on the board
~NMI: J2.29; also elsewhere on the board
~RAM_CS: U16.22 (CE#); also elsewhere on the board
~RAM_OE: U16.24 (OE#); also elsewhere on the board
~RES: J2.28, U19.34 (~RES), U21.4 (~RES); also elsewhere on the board
~ROM_CS: U15.22 (CE), U15.24 (OE); also elsewhere on the board
~UART_CS: U21.3 (~CS2); also elsewhere on the board
~VIA_CS: J2.33, U19.23 (~CS2); also elsewhere on the board

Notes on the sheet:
0x8000-0xBFFF (~ 16 KiB) [A15 & ~{A14}]
SCK
MAX232 is used for voltage level converting from 5V TTL to RS-232 +/- 12V. User can also directly hook up to the Tx / Rx ports available at both SYSTEM BUS (see other sheet) and the EXPANSION BUS (this sheet).
Signals are wired such that TxD <-> RxD ~{CTS} <-> ~{RTS} such that no null-modem cable is needed.
Versatile Interface Adapter
EXPANSION BUS, gives access to the PORTA and PORTB of the 65C22 Versatile Interface Adapter.
Asynchronous Communication Interface Adapter
Lower nibble of PORT A of the 65C22 is used for interfacing with an SD-CARD. SD-CARD is hosted on a 5V <-> 3v3 adapter card.
Note: the start-up vectors are at the top of memory, and are for that reason best confined to ROM.
Read Only Memory (ROM) Chip exposes its first 2 banks (8 KiB each) at 0xC000-0xFFFF. Via banking, any of the other 8 KiB banks can be set at 0xA000-0xBFFF.
Random Access Memory (RAM) Chip exposes its first 4 banks (8 KiB each) at 0x0000-0x7EFF (0x7XX is used for I/O). Via banking, any of the 8 KiB banks can be set at 0x8000-0x9FFFF.

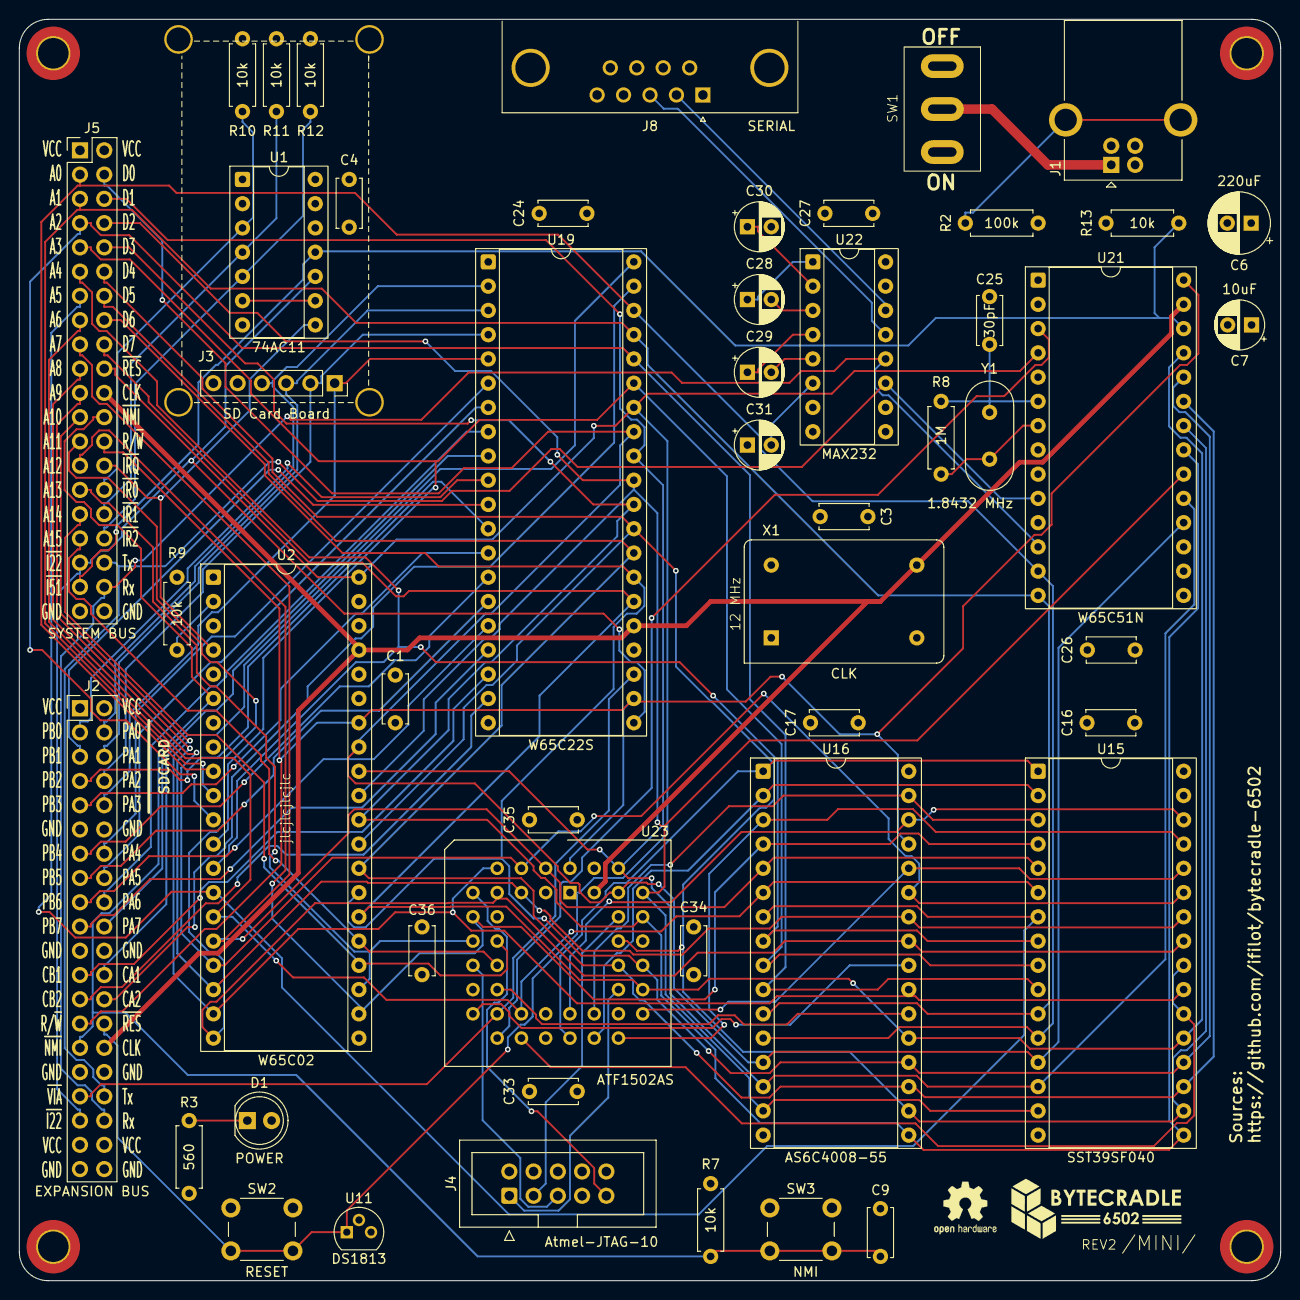
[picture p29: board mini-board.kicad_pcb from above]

Board: 4 copper layers, 132.1 x 132.1 mm, 56 parts (0 on the bottom side), 88 nets.

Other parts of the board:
G001: LOGO; bytecradle-logo
G002: OSHW-Logo2_7.3x6mm_SilkScreen

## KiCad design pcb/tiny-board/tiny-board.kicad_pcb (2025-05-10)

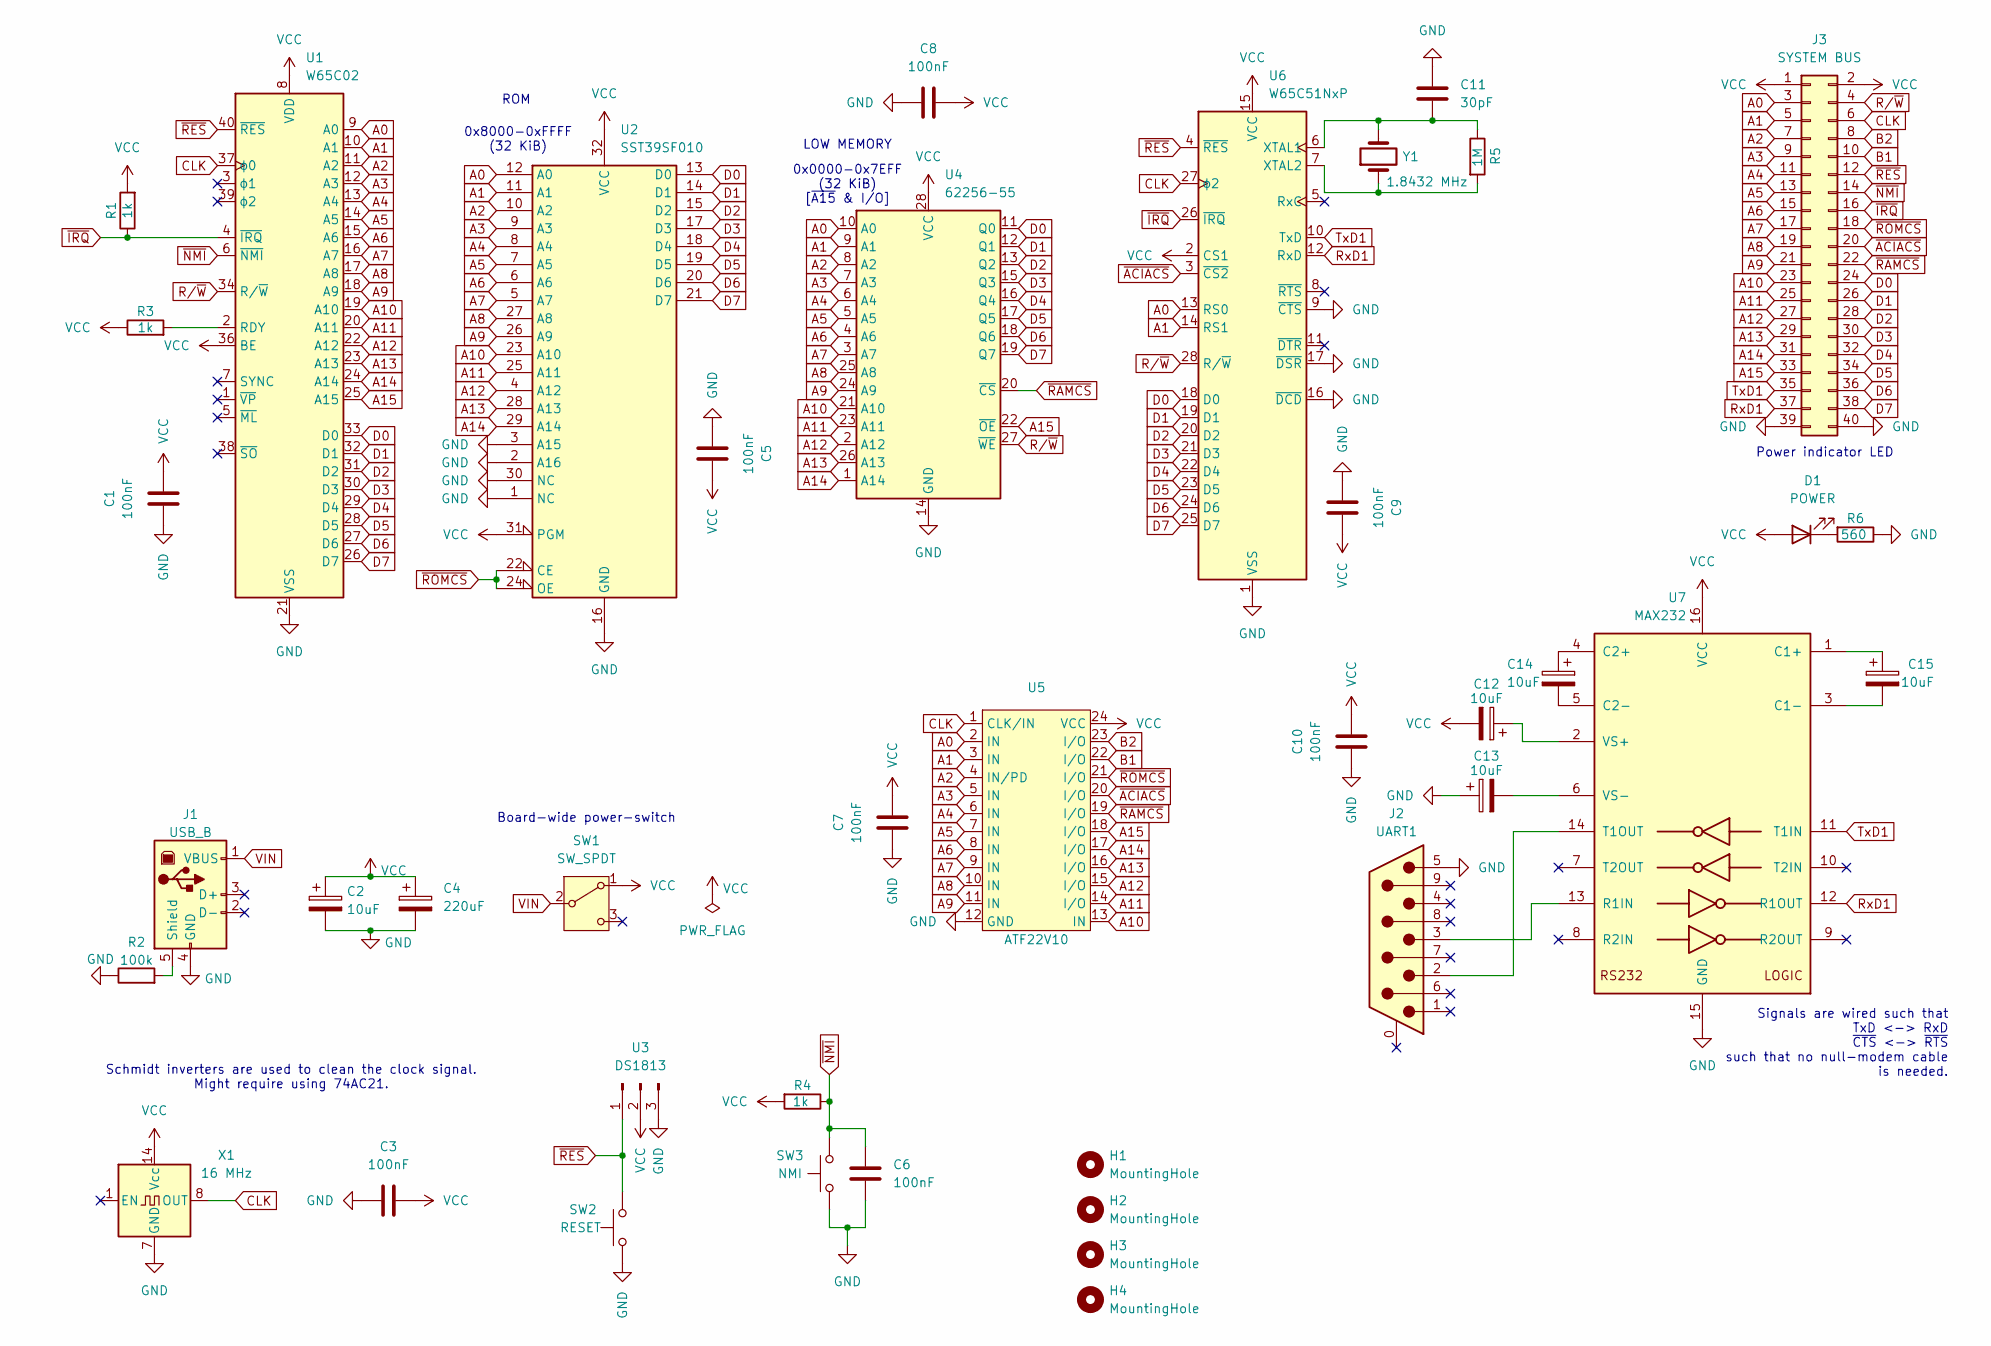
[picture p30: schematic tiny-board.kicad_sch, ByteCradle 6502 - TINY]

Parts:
C1, C3, C5, C6, C7, C8, C9, C10: 100nF; C_Disc_D5.0mm_W2.5mm_P5.00mm
C2, C12, C13, C14, C15: 10uF; CP_Radial_D5.0mm_P2.50mm
C4: 220uF; CP_Radial_D6.3mm_P2.50mm
C11: 30pF; C_Disc_D5.0mm_W2.5mm_P5.00mm
D1: POWER; LED_D5.0mm
H1, H2, H3, H4: MountingHole; MountingHole_3.2mm_M3_DIN965_Pad_TopOnly
J1: USB_B; USB_B_OST_USB-B1HSxx_Horizontal
J2: UART1; DSUB-9_Pins_Horizontal_P2.77x2.84mm_EdgePinOffset4.94mm_Hou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
J3: SYSTEM BUS; PinHeader_2x20_P2.54mm_Vertical
R1, R3, R4: 1k; R_Axial_DIN0207_L6.3mm_D2.5mm_P7.62mm_Horizontal
R2: 100k; R_Axial_DIN0207_L6.3mm_D2.5mm_P7.62mm_Horizontal
R5: 1M; R_Axial_DIN0207_L6.3mm_D2.5mm_P7.62mm_Horizontal
R6: 560; R_Axial_DIN0207_L6.3mm_D2.5mm_P7.62mm_Horizontal
SW1: SW_SPDT; power_switch
SW2: RESET; SW_PUSH_6mm
SW3: NMI; SW_PUSH_6mm
U1: W65C02; DIP-40_W15.24mm_Socket
U2: SST39SF010; DIP-32_W15.24mm_Socket
U3: DS1813; TO-92
U4: 62256-55; DIP-28_W15.24mm_Socket
U5: ATF22V10; DIP-24_W7.62mm_Socket
U6: W65C51NxP; DIP-28_W15.24mm_Socket
U7: MAX232; DIP-16_W7.62mm_Socket
X1: 16 MHz; Oscillator_DIP-14
Y1: 1.8432 MHz; Crystal_HC50_Vertical

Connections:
A0: J3.3, U1.9 (A0), U2.12 (A0), U4.10 (A0), U5.2 (IN), U6.13 (RS0)
A1: J3.5, U1.10 (A1), U2.11 (A1), U4.9 (A1), U5.3 (IN), U6.14 (RS1)
A2: J3.7, U1.11 (A2), U2.10 (A2), U4.8 (A2), U5.4 (IN/PD)
A3: J3.9, U1.12 (A3), U2.9 (A3), U4.7 (A3), U5.5 (IN)
A4: J3.11, U1.13 (A4), U2.8 (A4), U4.6 (A4), U5.6 (IN)
A5: J3.13, U1.14 (A5), U2.7 (A5), U4.5 (A5), U5.7 (IN)
A6: J3.15, U1.15 (A6), U2.6 (A6), U4.4 (A6), U5.8 (IN)
A7: J3.17, U1.16 (A7), U2.5 (A7), U4.3 (A7), U5.9 (IN)
A8: J3.19, U1.17 (A8), U2.27 (A8), U4.25 (A8), U5.10 (IN)
A9: J3.21, U1.18 (A9), U2.26 (A9), U4.24 (A9), U5.11 (IN)
A10: J3.23, U1.19 (A10), U2.23 (A10), U4.21 (A10), U5.13 (IN)
A11: J3.25, U1.20 (A11), U2.25 (A11), U4.23 (A11), U5.14 (I/O)
A12: J3.27, U1.22 (A12), U2.4 (A12), U4.2 (A12), U5.15 (I/O)
A13: J3.29, U1.23 (A13), U2.28 (A13), U4.26 (A13), U5.16 (I/O)
A14: J3.31, U1.24 (A14), U2.29 (A14), U4.1 (A14), U5.17 (I/O)
A15: J3.33, U1.25 (A15), U4.22 (~OE), U5.18 (I/O)
B1: J3.10, U5.22 (I/O)
B2: J3.8, U5.23 (I/O)
CLK: J3.6, U1.37 (ϕ0), U5.1 (CLK/IN), U6.27 (ϕ2), X1.8 (OUT)
D0: J3.24, U1.33 (D0), U2.13 (D0), U4.11 (Q0), U6.18 (D0)
D1: J3.26, U1.32 (D1), U2.14 (D1), U4.12 (Q1), U6.19 (D1)
D2: J3.28, U1.31 (D2), U2.15 (D2), U4.13 (Q2), U6.20 (D2)
D3: J3.30, U1.30 (D3), U2.17 (D3), U4.15 (Q3), U6.21 (D3)
D4: J3.32, U1.29 (D4), U2.18 (D4), U4.16 (Q4), U6.22 (D4)
D5: J3.34, U1.28 (D5), U2.19 (D5), U4.17 (Q5), U6.23 (D5)
D6: J3.36, U1.27 (D6), U2.20 (D6), U4.18 (Q6), U6.24 (D6)
D7: J3.38, U1.26 (D7), U2.21 (D7), U4.19 (Q7), U6.25 (D7)
GND: C1.2, C2.2, C3.2, C4.2, C5.2, C6.2, C7.2, C8.2, C9.2, C10.2, C11.1, C13.1, J1.4 (GND), J2.5, J3.39, J3.40, R2.1, R6.1, SW2.1, SW3.1, U1.21 (VSS), U2.1 (NC), U2.2 (A16), U2.3 (A15), U2.16 (GND), U2.30 (NC), U3.3, U4.14 (GND), U5.12 (GND), U6.1 (VSS), U6.9 (~CTS), U6.16 (~DCD), U6.17 (~DSR), U7.15 (GND), X1.7 (GND)
unnamed: D1.1 (K), R6.2
unnamed: J1.5 (Shield), R2.2
unnamed: R3.2, U1.2 (RDY)
unnamed: C11.2, R5.1, U6.6 (XTAL1), Y1.2
unnamed: R5.2, U6.7 (XTAL2), Y1.1
unnamed: C15.1, U7.1 (C1+)
unnamed: C15.2, U7.3 (C1-)
unnamed: C14.1, U7.4 (C2+)
unnamed: C14.2, U7.5 (C2-)
unnamed: J2.3, U7.13 (R1IN)
unnamed: J2.2, U7.14 (T1OUT)
unnamed: C12.1, U7.2 (VS+)
unnamed: C13.2, U7.6 (VS-)
RxD1: J3.37, U6.12 (RxD), U7.12 (R1OUT)
R/~W: J3.4, U1.34 (R/~W), U4.27 (~WE), U6.28 (R/~W)
TxD1: J3.35, U6.10 (TxD), U7.11 (T1IN)
VCC: C1.1, C2.1, C3.1, C4.1, C5.1, C7.1, C8.1, C9.1, C10.1, C12.2, D1.2 (A), J3.1, J3.2, R1.2, R3.1, R4.2, SW1.1 (A), U1.8 (VDD), U1.36 (BE), U2.31 (PGM), U2.32 (VCC), U3.2, U4.28 (VCC), U5.24 (VCC), U6.2 (CS1), U6.15 (VCC), U7.16 (VCC), X1.14 (Vcc)
VIN: J1.1 (VBUS), SW1.2 (B)
~ACIACS: J3.20, U5.20 (I/O), U6.3 (~CS2)
~IRQ: J3.16, R1.1, U1.4 (~IRQ), U6.26 (~IRQ)
~NMI: C6.1, J3.14, R4.1, SW3.2, U1.6 (~NMI)
~RAMCS: J3.22, U4.20 (~CS), U5.19 (I/O)
~RES: J3.12, SW2.2, U1.40 (~RES), U3.1, U6.4 (~RES)
~ROMCS: J3.18, U2.22 (CE), U2.24 (OE), U5.21 (I/O)

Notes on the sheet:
LOW MEMORY
0x0000-0x7EFF (32 KiB) [~{A15} & I/O]
0x8000-0xFFFF (32 KiB)
Schmidt inverters are used to clean the clock signal. Might require using 74AC21.
Power indicator LED
ROM
Signals are wired such that TxD <-> RxD ~{CTS} <-> ~{RTS} such that no null-modem cable is needed.
Board-wide power-switch

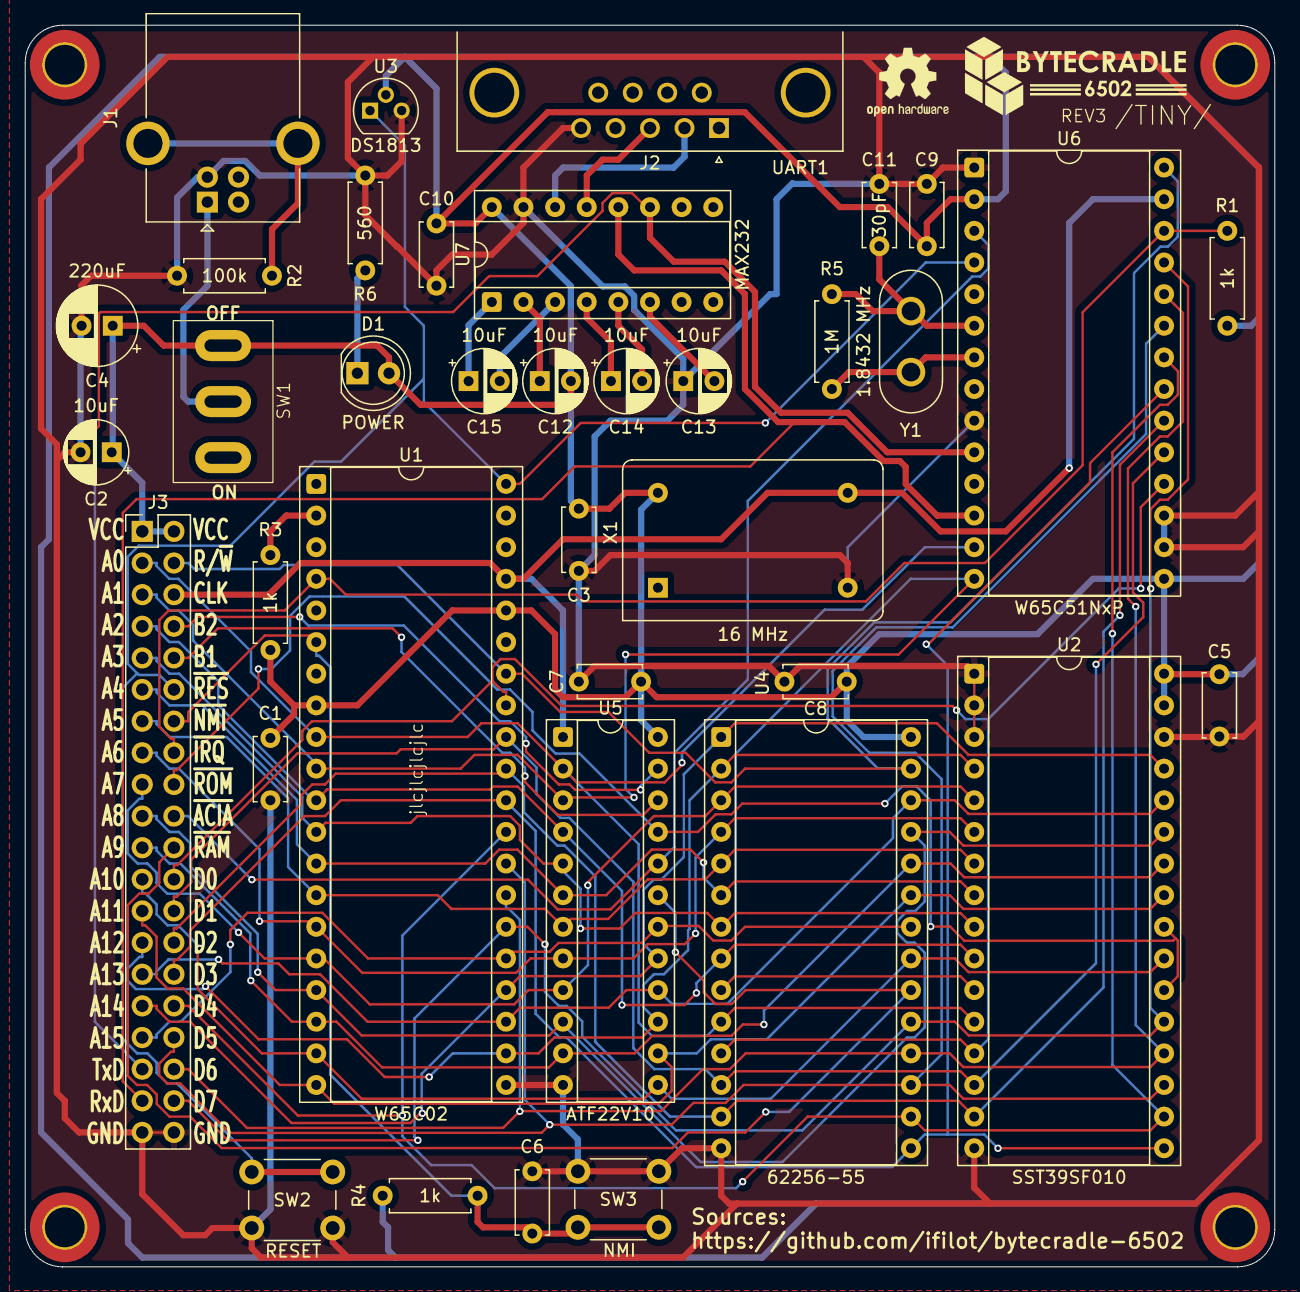
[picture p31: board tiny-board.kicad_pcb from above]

Board: 2 copper layers, 100.3 x 99.7 mm, 42 parts (0 on the bottom side), 52 nets.

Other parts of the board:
G002: OSHW-Logo2_7.3x6mm_SilkScreen

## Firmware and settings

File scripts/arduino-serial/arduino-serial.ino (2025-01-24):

void setup() {
  // Initialize Serial (USB connection to computer)
  Serial.begin(115200);

  // Initialize Serial1 (Hardware serial for incoming data)
  Serial1.begin(115200); // Match the baud rate of your ACIA
}

void loop() {
  // Forward data from Serial1 to Serial
  if (Serial1.available()) {
    char incomingByte = Serial1.read();
    Serial.write(incomingByte); // Send the byte to the computer
  }

  // Optionally, forward data from Serial to Serial1 (e.g., to send commands)
  if (Serial.available()) {
    char outgoingByte = Serial.read();
    Serial1.write(outgoingByte); // Send the byte to the ACIA or other device
  }
}

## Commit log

2025-01-08 Initial lay-out PCB
    [bytecradle-6502-single-board.kicad_pcb, bytecradle-6502-single-board.kicad_sch]
2025-01-08 Tuning design
    [bytecradle-6502-single-board.kicad_pcb, bytecradle-6502-single-board.kicad_sch]
2025-01-08 Adding details
    [bytecradle-6502-single-board.kicad_pcb]
2025-01-09 Pre-routing commit
    [bytecradle-6502-single-board.dsn, bytecradle-6502-single-board.kicad_pcb]
2025-01-09 Finalizing lay-out
    [bytecradle-6502-single-board-B_Cu.gbr, bytecradle-6502-single-board-B_Mask.gbr, bytecradle-6502-single-board-B_Paste.gbr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]
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2025-01-15 Adding program and expansio board
    [bytecradle-6502-expansion-board-B_Cu.gbr, bytecradle-6502-expansion-board-B_Mask.gbr, bytecradle-6502-expansion-board-B_Paste.gbr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]
2025-01-17 Adding Arduino interface and test code for ACIA
    [bytecradle-6502-single-board.kicad_sch, rom.cfg]
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2025-01-21 Adding Hello World program on different ROM bank
    [rom.cfg]
2025-01-21 Initial attempt adding C program
    [sbc.cfg]
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2025-01-25 Further redesigning boards
    [bytecradle-6502-single-board.dsn, bytecradle-6502-single-board.kicad_pcb, bytecradle-6502-single-board.kicad_sch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]
2025-01-25 Fixing mistake
    [bytecradle-6502-single-board.dsn, bytecradle-6502-single-board.kicad_pcb, bytecradle-6502-single-board.kicad_sch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]
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2025-01-26 Fixing errors and finalizing SBC design
    [bytecradle-6502-single-board-B_Cu.gbr, bytecradle-6502-single-board-B_Mask.gbr, bytecradle-6502-single-board-B_Paste.gbr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]
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2025-01-26 Revising board and adding logo
    [bytecradle-6502-single-board-B_Cu.gbr, bytecradle-6502-single-board-B_Mask.gbr, bytecradle-6502-single-board-B_Paste.gbr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]
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2025-02-01 Implementing memory write routine to monitor
    [rom.cfg]
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2025-02-07 Refactoring code, fixing bugs in putdec and assembly routines
    [rom.cfg]
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2025-02-07 Adding VGA interface prototype
    [propeller-vga-B_Cu.gbr, propeller-vga-B_Mask.gbr, propeller-vga-B_Paste.gbr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]
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2025-02-09 Updating design for V2
    [bytecradle-6502-single-board.kicad_pcb]
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2025-02-15 Fixing a few bugs, bug in assembler still remaining
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2025-02-15 Adding SD card to emulator
    [sbc.cfg]
2025-02-16 Trying to implement SD card routines in C
    [sbc.cfg]
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2025-02-16 Relocating source code and expanding emulator
    [sbc.cfg]
2025-02-22 Adding GPU prototype board
    [propeller-vga-board-B_Cu.gbr, propeller-vga-board-B_Mask.gbr, propeller-vga-board-B_Paste.gbr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]
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2025-02-23 Adding file finding routine
    [sbc.cfg]
2025-02-23 Adding testhat for VGA via Parallax Propeller
    [propeller-40k-testhat-B_Cu.gbr, propeller-40k-testhat-B_Mask.gbr, propeller-40k-testhat-B_Paste.gbr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]
2025-02-28 Trying to implement .COM execution
    [rom.cfg, sbc.cfg]
2025-03-01 Launching programs from command line
    [rom.cfg]
2025-03-01 Implementing loading of external C and ASM programs
    [prog.cfg, rom.cfg, sbc.cfg]
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2025-03-02 Adding mandelbrot set generator
    [prog.cfg]
2025-03-02 Creating simple test program
    [rom.cfg]
2025-03-06 Integrating NCURSES into emulator
    [mini-board-B_Cu.gbr, mini-board-B_Mask.gbr, mini-board-B_Paste.gbr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]
2025-03-25 Saving tiny board design
    [romram.kicad_sch, tiny-board.kicad_pcb, tiny-board.kicad_sch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]
2025-03-28 Revising TINY board and creating test ROM for TINY board
    [romram.kicad_sch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]
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2025-03-31 Revising single board layout
    [bytecradle-6502-single-board.kicad_pcb, bytecradle-6502-single-board.kicad_sch, romram.kicad_sch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]
2025-03-31 Initial commit bitbang SD-card routines
    [bytecradle-6502-single-board.dsn, bytecradle-6502-single-board.kicad_pcb, bytecradle-6502-single-board.kicad_sch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]
2025-04-01 Fixing bitbanged SD-card SPI protocol
2025-04-01 Cleaning repository and completing SD-card reading using bitbang SPI
    [bytecradle-6502-expansion-board-B_Cu.gbr, bytecradle-6502-expansion-board-B_Mask.gbr, bytecradle-6502-expansion-board-B_Paste.gbr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]
2025-04-12 Revising TINY board and writing CUPL
    [romram.kicad_sch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]
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2025-04-15 Creating testrom for SBC
    [rom.cfg]
2025-04-19 Integrating CIA CPLD for tiny board
    [rom.cfg, tiny-board.kicad_pcb, tiny-board.kicad_sch]
2025-04-19 Revising board and integrating DS1813
    [tiny-board-B_Cu.gbr, tiny-board-B_Mask.gbr, tiny-board-B_Paste.gbr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]
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2025-04-26 Complete overhaul of emulator (#1)
    * Initial commit revision emulator
    * Fixing input/output
    * Adding clock routine
    * Integrating ACIA into emulator
    * Adding VIA chip
    * Adding SD-card interface
    * Implementing SD-card in emulator and creating mini board testrom
    * Fixing error in GA
    * Fixing capitalization in headers
    * Adding headers
    * Adding dependency
    * Hooking minirom to emulator
    [rom.cfg]
2025-04-28 Fixing position hole
    [mini-board.kicad_pcb]
2025-04-28 Expanding documentation and fixing bugs description in assembler
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2025-04-29 Expanding documentation and adding CUPL for mini board
    [tinyboard_enclosure_tray.stl]
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2025-05-01 Revising tinyboard (REV2) and adding daughterboard with LEDs
    [tiny-board-B_Cu.gbr, tiny-board-B_Mask.gbr, tiny-board-B_Paste.gbr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]
2025-05-02 Initial commit miniboard revision
    [mini-board.kicad_pcb, mini-board.kicad_sch, rom.cfg]
2025-05-03 Fixing bugs in CPLD and removing minimalistic testrom
    [mini-board.kicad_sch, peripherals.kicad_sch, rom.cfg]
2025-05-03 Implementing banking in emulator
    [miniboard_enclosure_tray.stl]
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2025-05-03 Adding documentation to schematics
    [mini-board.dsn, mini-board.kicad_pcb, mini-board.kicad_sch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]
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2025-05-05 Fixing width of VIN
    [mini-board-B_Cu.gbr, mini-board-B_Mask.gbr, mini-board-B_Paste.gbr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]
2025-05-09 Adding 10k resistor to IRQ51
    [mini-board-B_Cu.gbr, mini-board-B_Mask.gbr, mini-board-B_Paste.gbr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]
2025-05-10 Making small changes to tiny board and updating documentation
    [tiny-board.kicad_pcb, tiny-board.kicad_sch]
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2025-05-12 Exposing BCOS ROM and modifying README file
    [mini-board-B_Cu.gbr, mini-board-B_Mask.gbr, mini-board-B_Paste.gbr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]
2025-05-12 Adding hardware customization for ACIA
    [mini-board.kicad_pcb]
2025-05-14 Adding a delay routine
    [rom.cfg]
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2025-06-28 Adjusting board for FPGA daughterboard
    [tinyboard_enclosure_tray_spareout.stl]
2026-04-06 Fixing bugs in jumptable
    [sbc.cfg]
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2026-04-06 Updating README and names
    [miniboard_baseplate.stl, tinyboard_baseplate.stl, tinyboard_baseplate_spareout.stl]
2026-09-18 Upgrading schematics to KiCAD 10
    [mini-board.kicad_sch, peripherals.kicad_sch]
